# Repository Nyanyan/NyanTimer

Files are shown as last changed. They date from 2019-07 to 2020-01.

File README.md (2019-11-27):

# NyanTimer
DIY Stackmat Timer for cubing

**日本語は下部にあります。**



<!-- TOC -->

- [NyanTimer](#nyantimer)
    - [オープンソースバージョンの使い方](#オープンソースバージョンの使い方)
        - [電池](#電池)
        - [電源](#電源)
        - [ボタン](#ボタン)
        - [タイマースタート・ストップ](#タイマースタート・ストップ)
        - [インスペクションタイム計測](#インスペクションタイム計測)
        - [ラップタイム計測](#ラップタイム計測)
        - [ハック](#ハック)
        - [NyanTimerライブラリ](#nyantimerライブラリ)
    - [開発環境](#開発環境)
    - [技術的な解説](#技術的な解説)
        - [ハードウェア](#ハードウェア)
            - [ボディ](#ボディ)
            - [タッチセンサ](#タッチセンサ)
            - [その他の入出力部品](#その他の入出力部品)
        - [ソフトウェア](#ソフトウェア)
            - [全体的な処理](#全体的な処理)
            - [信号](#信号)
    - [ファイル](#ファイル)
        - [board](#board)
        - [body](#body)
        - [program](#program)
        - [README](#readme)
    - [参考資料](#参考資料)

<!-- /TOC -->

## オープンソースバージョンの使い方

### 電池

左右にある写真の蓋を取って、CR2450を入れます。

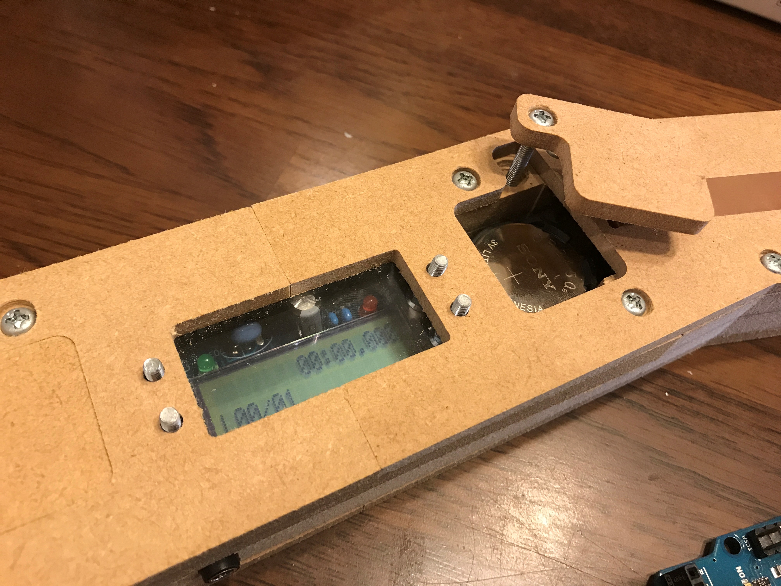
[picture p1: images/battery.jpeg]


ちょっと蓋が取りにくいです。裏側に出ているネジを押しつつ表側でネジの上を押さえると取りやすいです。

### 電源

タイマーにあるスライドスイッチで電源が入ります。これも少し扱いにくいです(ごめんなさい)

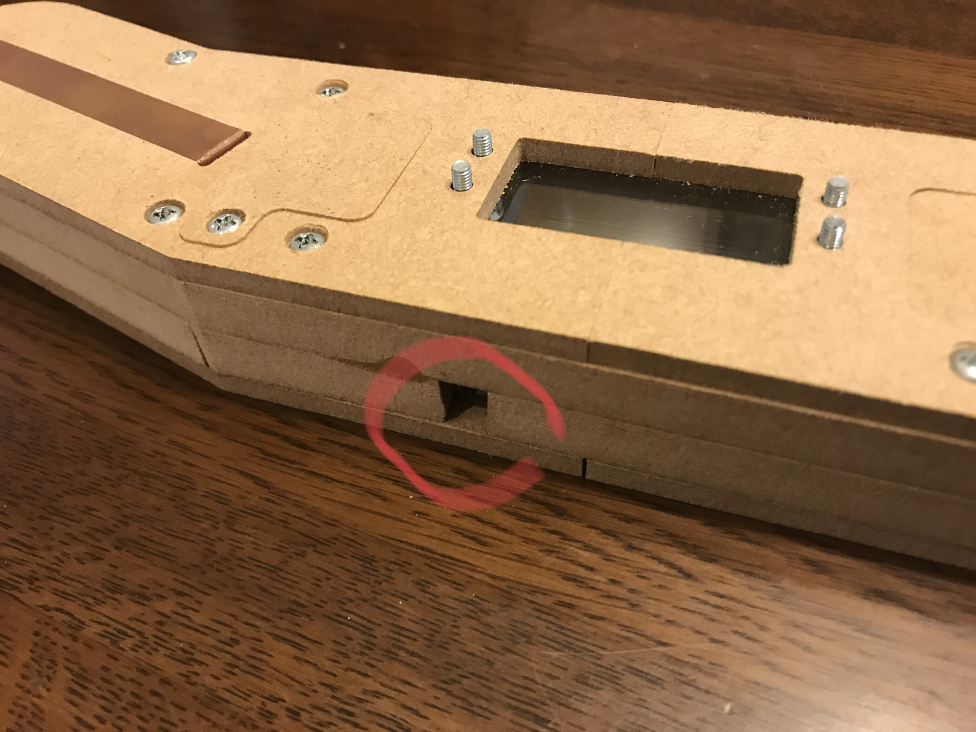
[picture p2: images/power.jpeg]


秋月にいい感じのスイッチが見当たらなくて…

### ボタン

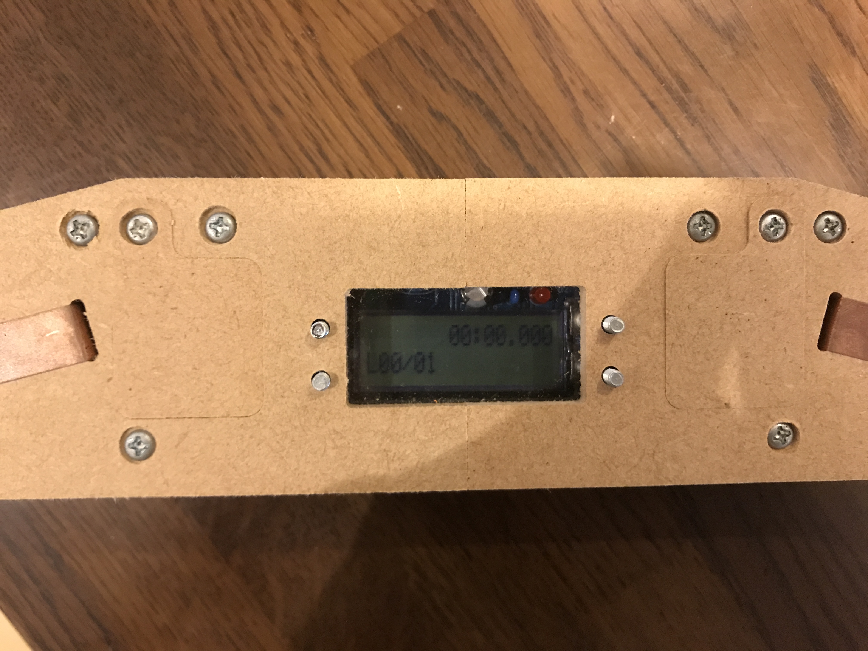
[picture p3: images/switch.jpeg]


* 左上: インスペクションタイム計測モード切り替え

* 左下: タイムリセット

* 右上: ラップ計測回数調整(アップ)

* 右下: ラップ計測回数調整(ダウン)

### タイマースタート・ストップ

manualをご覧ください。

### インスペクションタイム計測

manualをご覧ください。

### ラップタイム計測

manualをご覧ください。

### ハック

manualをご覧ください。

### NyanTimerライブラリ

manualをご覧ください。

## 開発環境

Visual Studio Code

Arduino IDE

Autodesk Eagle

Autodesk Fusion 360

## 技術的な解説

### ハードウェア

基板について詳しいことはboard-vXの中のEagleのデータをご覧ください(回路図描くのが下手でごめんなさい)。簡単に説明すると、Arduinoから各部品に接続しているだけです。

ボディとタッチセンサについてのみ、少し細かく説明をします。その後、その他の部品の概要を少し書きます。

####  ボディ

ボディはAutodesk Fusion 360で設計し、CNCフライス盤で切り出しました ~~(今後レーザーカッターでの出力に方針転換する予定)~~  今後は3Dプリンタで試作した後、金型作って大量生産する予定です。

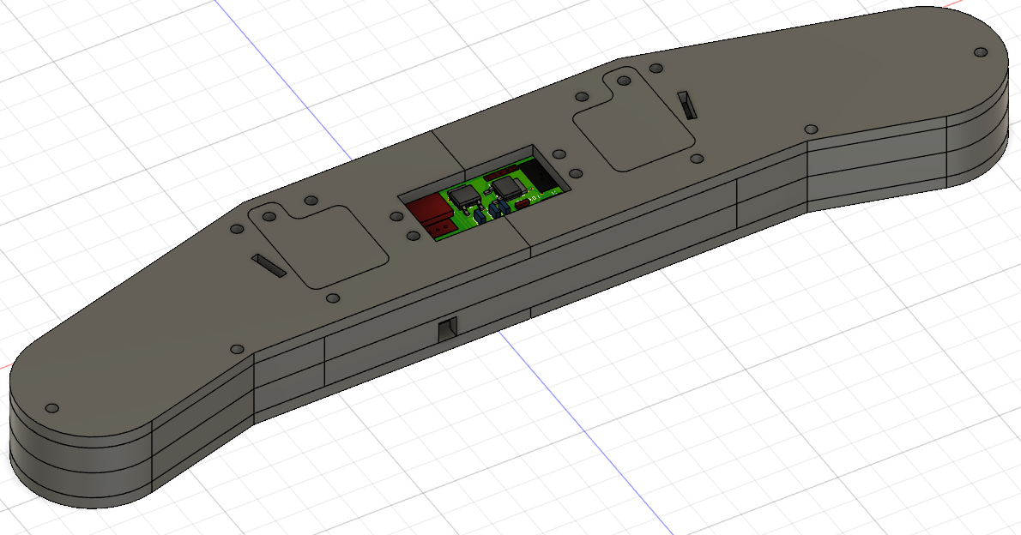
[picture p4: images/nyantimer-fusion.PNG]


#### タッチセンサ

スタックタイマーのタッチセンサは静電容量方式のセンサです。これについて、今回は自作しました。

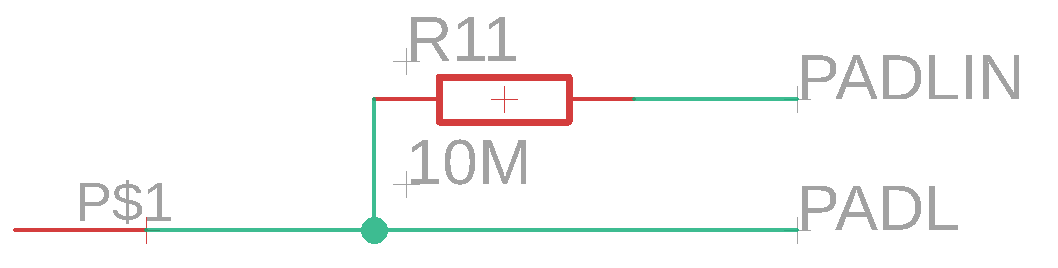
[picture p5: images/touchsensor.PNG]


少々図が汚いですが勘弁してください。

この図でP$1となっているところがタッチパッドの部分です。PADLINから5Vを定期的に入れて、PADLにかかる電圧を調べます。この時、タッチパッドに手を置いているとタッチパッドと手とがそれぞれ極板となって擬似的なコンデンサが成立し、このコンデンサを充電することになります。そのためにPADLがHIGHになるまでの時間が延び、タッチパッドに手が置かれたことを判定できます。

詳しい静電容量方式のセンサについては以下を参照してください。

https://www.fujiele.co.jp/semiconductor/ti/tecinfo/news201707210000/

http://nn-hokuson.hatenablog.com/entry/2017/03/22/200454

なお、電池が多少減ってきても正確にタッチセンサが動くよう、電源投入時にPADLにかかる電圧を測定し、それに1未満の係数を掛けた値をPADLがHIGHであると判定する閾値にしました。

余談ですが、キューブの大会ではタイマーで1/1000秒まで計測可能であるにも関わらず、公式タイムには1/100秒までしか書きません。この理由を私は詳しく知りませんが、このセンサの「時間を計測することで近接を感知する」特性によるところもあるのではないかと個人的に思っています。

#### その他の入出力部品

ブザー

タクトスイッチ

液晶(16文字x2行)

### ソフトウェア

#### 全体的な処理

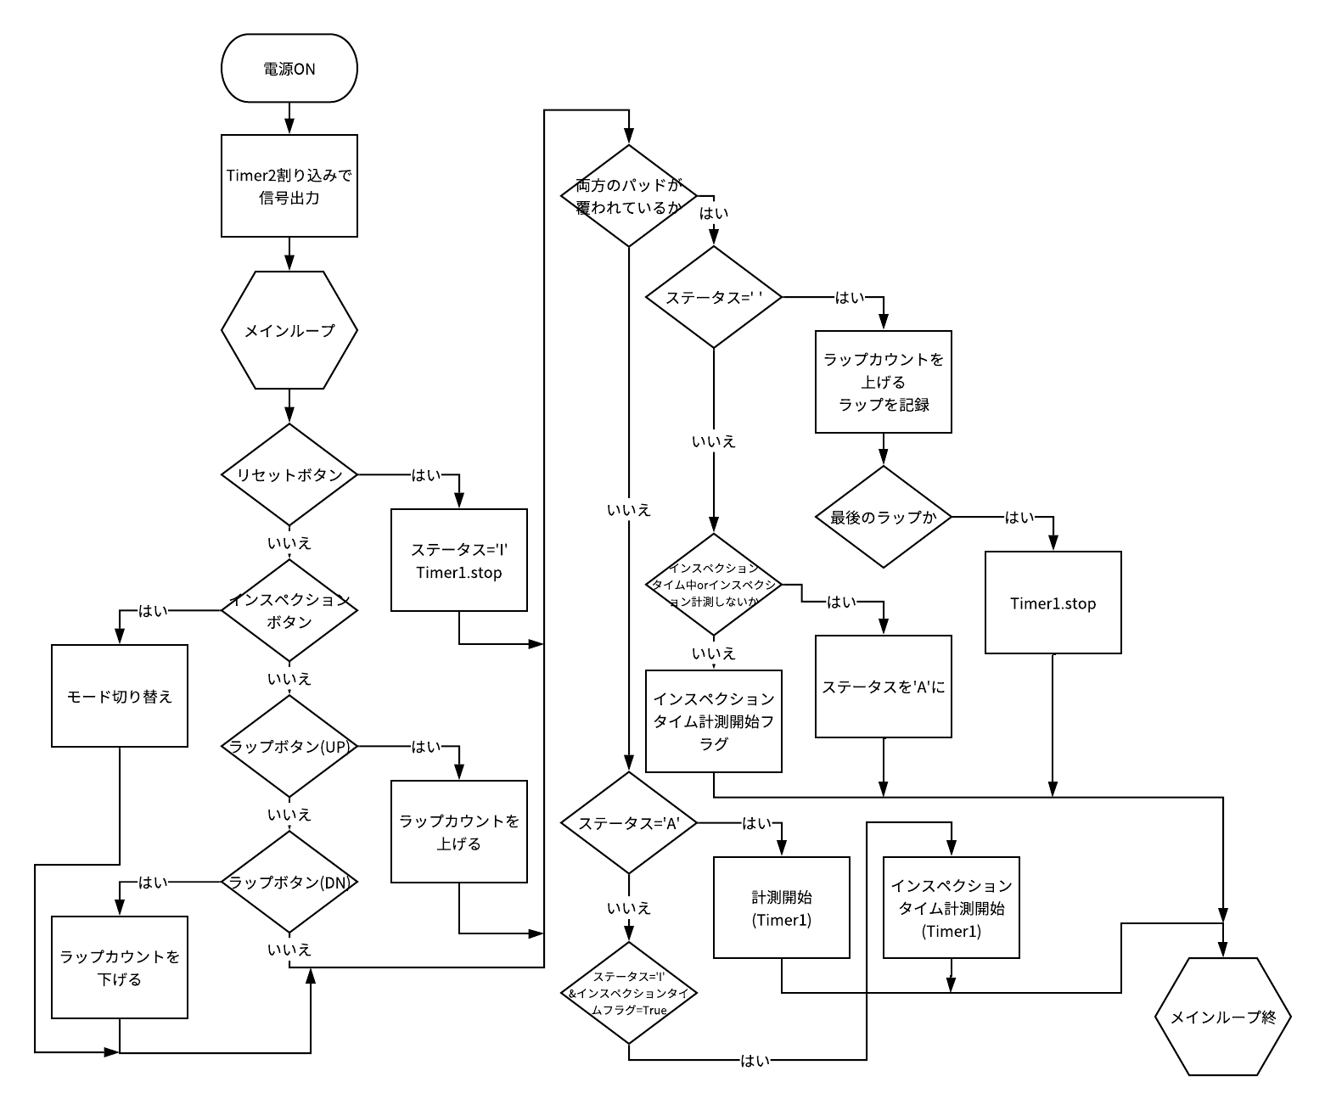
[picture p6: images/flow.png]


なぜか繰り返し記号が使えなかったので適当に六角形で代用です。

プログラム中では左側がbutton()で、右側がtimer()です。

これ以外にも色々複雑に処理はしていますが、まあ大体はこんな感じです。

マイコンは要するにArduinoなので、使えるタイマーはTimer1とTimer2の２つのみです。そのため、Timer2は信号の割り込み処理にずっと使うとして、時間計測とインスペクションタイム計測をTimer1でやっています。

#### 信号

信号はこちらなどを参考にしました。

https://github.com/fw42/atmel/tree/master/stackmat

簡単に日本語で書きます。私は通信には詳しくないので、正確には上を参照してください。

* 信号はRS232
* 1200bps
* データビットは8つ(ステータス、時刻、チェックサム)
* パリティビットなし
* 終了ビットは一つ(LF)

送るデータ

* 1: ステータスのデータ('I', 'A', 'S', 'L', 'R', 'C', ' ')
* 2-7: 時刻のデータ(1:23.45なら‘12345’)
* 8: チェックサム(ASCIIコードで64+タイムの各数字の和, 上の例ならASCIIで79=O)
* 9: CR(ASCIIコード0x0D)
* 10: LF(ASCIIコード0x0A)

1番目、ステータスのデータは、

* ‘I’: タイマー初期化(リセットされた状態)
* ‘A’: タイマースタート直前(パッドを手で押さえて、話したらスタートできる状態)
* ‘ ’: 計測中
* ‘S’: タイム計測完了
* ‘L’: 左パッドが覆われている状態
* ‘R’: 右パッドが覆われている状態
* ‘C’: 両方のパッドが覆われている状態

ただし、NyanTimerでは‘C’は特に必要ないために実装していません(以前は‘R’,‘L’も実装していませんでしたが、CS Timerのインスペクションタイム計測機能であると便利とわかり実装しました)。

## ファイル

### board

基板です。2019/09/05現在、v4-v7までのボードの動作確認がとれています。

### body

外装

Fusion360のファイルとobjとstlファイル

body-v2内のncファイルはPartsTogether内のが最新版です

### program

プログラムとライブラリ

~~中に“calibration”とついたものがありますが、これはタッチセンサで電源投入時に自動でキャリブレーションを行うプログラムです。2019/09/24現在キャリブレーションは試用の機能なので分けて開発しています(Gitを使いこなせていない)~~

2019/10/11追記: キャリブレーション機能はデフォルトの機能になりました。古いプログラムは“archive”内に移動しました。

~~“withfunc”のついたプログラムは、NyanTimer専用関数郡を別に書いたもので、2019/10/11現在試用のプログラムです。~~ 2019/10/14現在、デフォルトのプログラムになりました。

### README

これ

## 参考資料

信号関係(私がまとめた日本語記事): https://qiita.com/Nyanyan_Cube/items/e517e71cf5c4e2aaf1e5

信号関係(英語記事): https://github.com/fw42/atmel/tree/master/stackmat

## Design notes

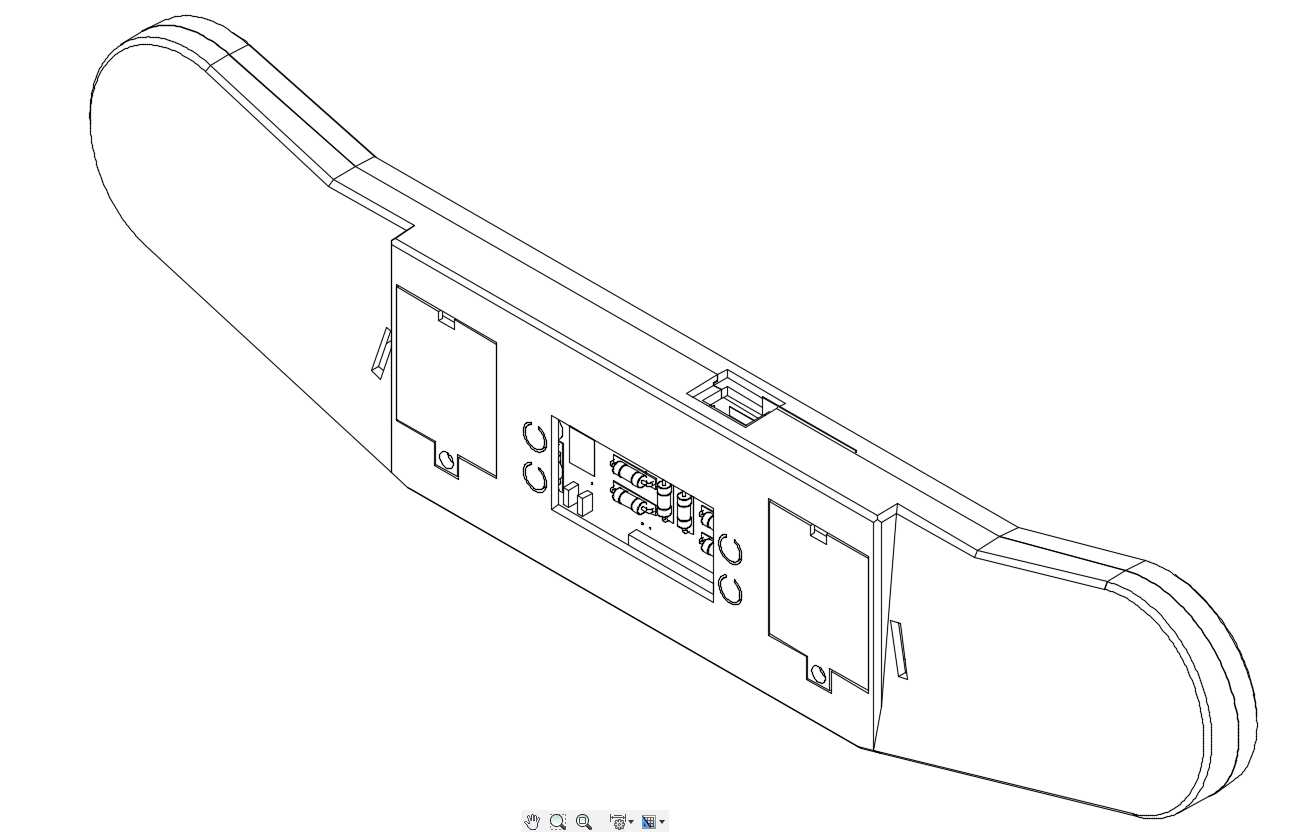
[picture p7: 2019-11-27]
NyanTimer1/images/bodyv4-2.PNG

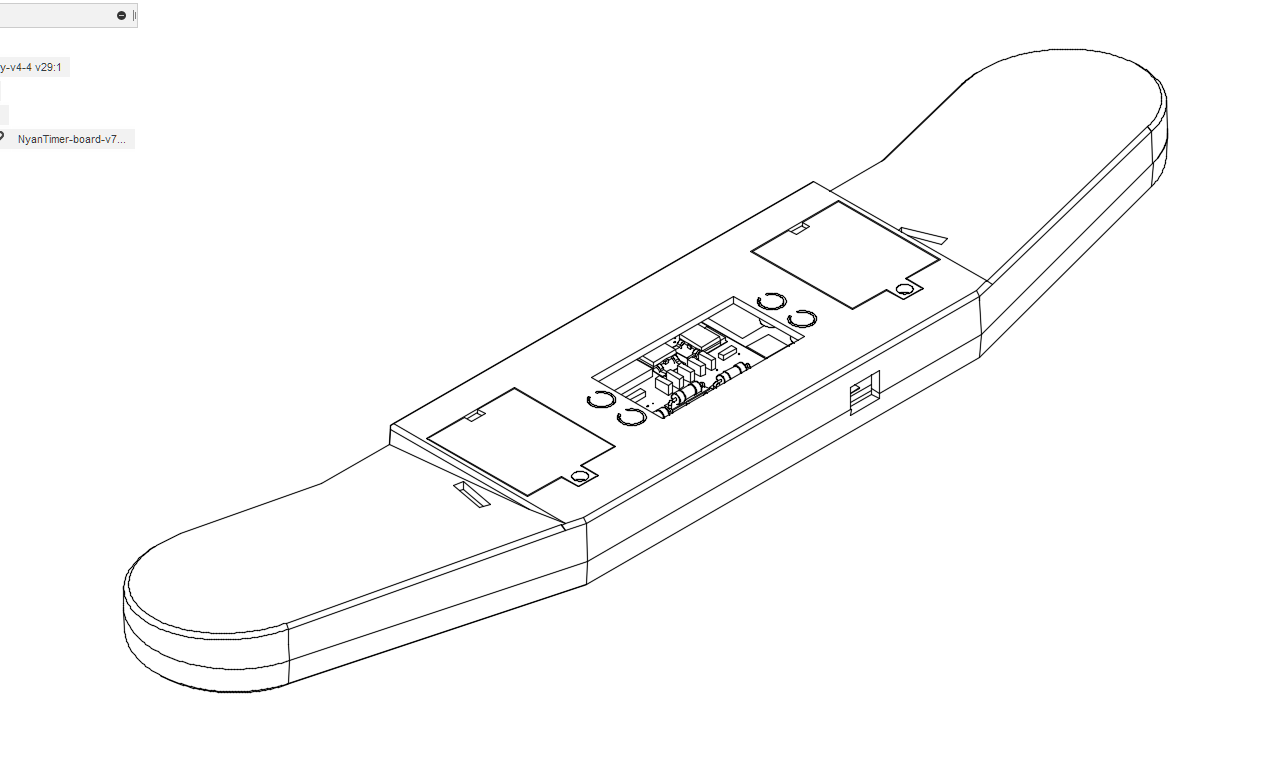
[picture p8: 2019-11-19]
NyanTimer1/images/bodyv4-1.PNG

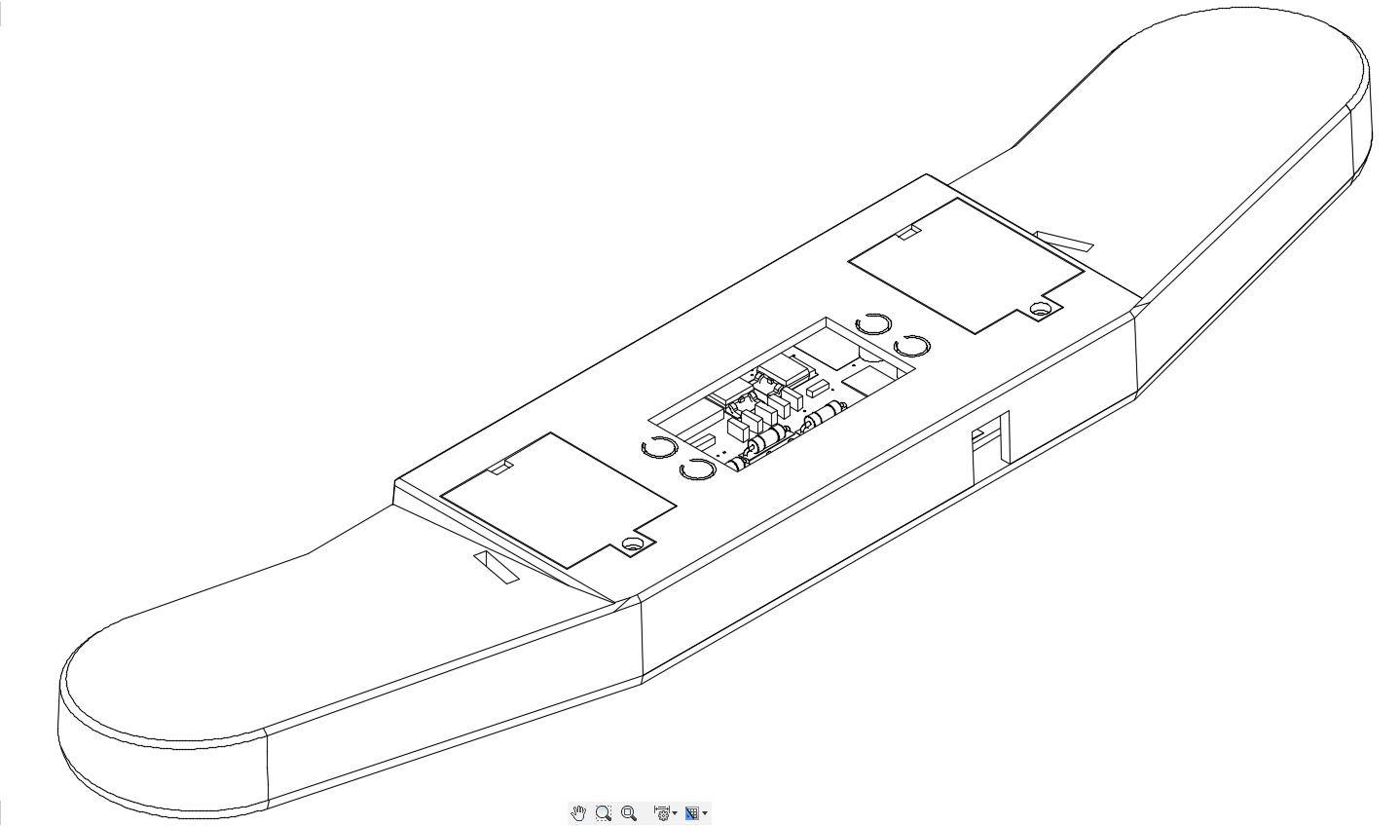
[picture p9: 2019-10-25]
NyanTimer1/images/drawing-bodyv3.PNG

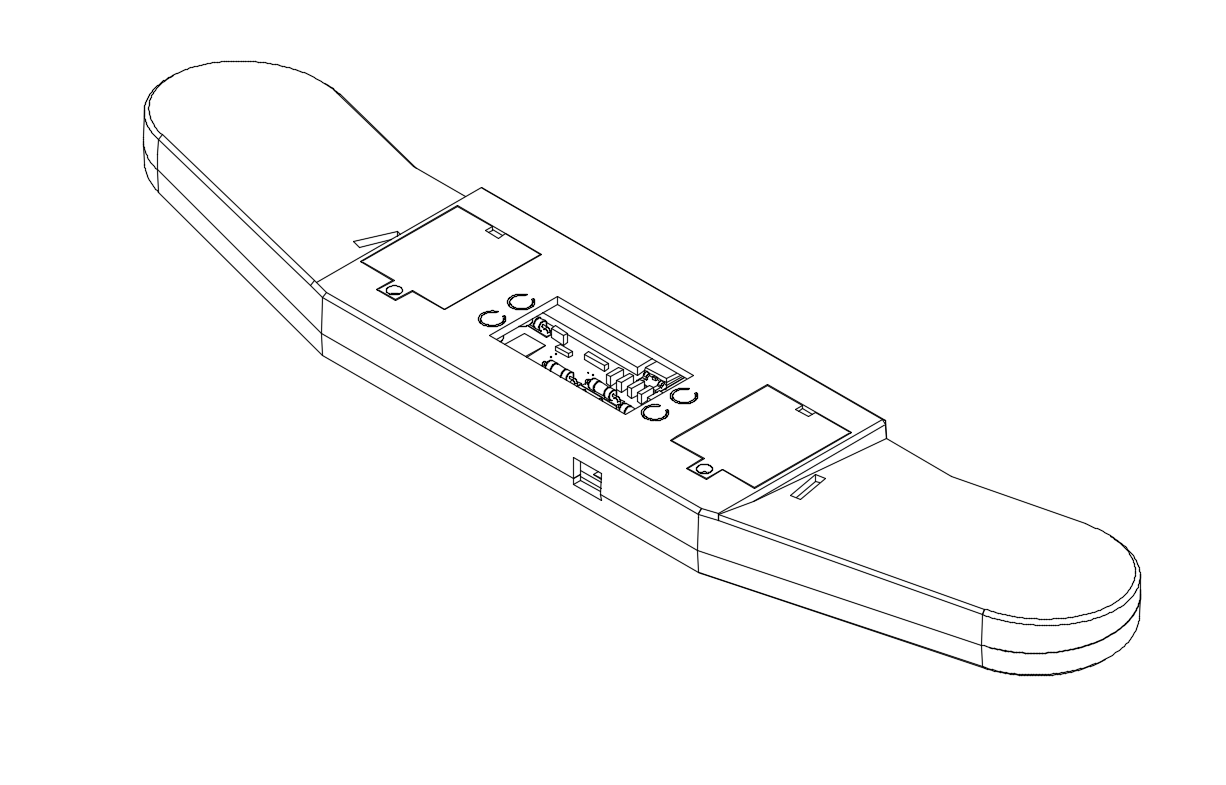
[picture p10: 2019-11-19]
NyanTimer1/images/後.PNG

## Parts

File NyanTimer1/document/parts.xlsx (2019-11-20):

NyanTimer 部品表 | 番号 | 部品名 | 仕様 | 単価 | 個数 | 小計 | URL
 | 1 | ATMEGA328P | ブートローダー書込済 | 320 | 1 | 320 | http://akizukidenshi.com/catalog/g/gI-12774/
 | 2 | 推奨発振子 | 16MHz | 30 | 1 | 30 | http://akizukidenshi.com/catalog/g/gP-08671/
 | 3 | 液晶 | 16x2 | 450 | 1 | 450 | http://akizukidenshi.com/catalog/g/gP-11916/
 | 4 | 電池ボックス | CR2450 | 70 | 2 | 140 | http://akizukidenshi.com/catalog/g/gP-09413/
 | 5 | レギュレータ | 5V | 30 | 1 | 30 | http://akizukidenshi.com/catalog/g/gI-11237/
 | 6 | レギュレータ | 3.3V | 50 | 1 | 50 | http://akizukidenshi.com/catalog/g/gI-11299/
 | 7 | RS232レベル変換IC | ADM3202ANZ | 450 | 0.5 | 225 | http://akizukidenshi.com/catalog/g/gI-03030/
 | 8 | イヤホンジャック |  | 50 | 1 | 50 | http://akizukidenshi.com/catalog/g/gC-02460/
 | 9 | ブザー | 16mm | 100 | 1 | 100 | http://akizukidenshi.com/catalog/g/gP-09644/
 | 10 | LED | 3mm | 10 | 2 | 20 | http://akizukidenshi.com/catalog/g/gI-11577/
 | 11 | タクトスイッチ |  | 10 | 4 | 40 | http://akizukidenshi.com/catalog/g/gP-03647/
 | 12 | スライドスイッチ |  | 30 | 1 | 30 | http://akizukidenshi.com/catalog/g/gP-08789/
 | 13 | 抵抗 | 10k | 1 | 7 | 7
 | 14 | 抵抗 | 1k | 1 | 2 | 2
 | 15 | 抵抗 | 10M | 1 | 2 | 2
 | 16 | コンデンサ | 0.1u | 10 | 12 | 120
 | 17 | コンデンサ | 1u | 10 | 2 | 20
 | 18 | コンデンサ | 2.2u以上 | 10 | 2 | 20
 | 19 | コンデンサ | 0.22u | 10 | 2 | 20
 | 20 | 電池 | CR2450 | 260 | 2 | 520 | https://www.yodobashi.com/product/100000001001156421/

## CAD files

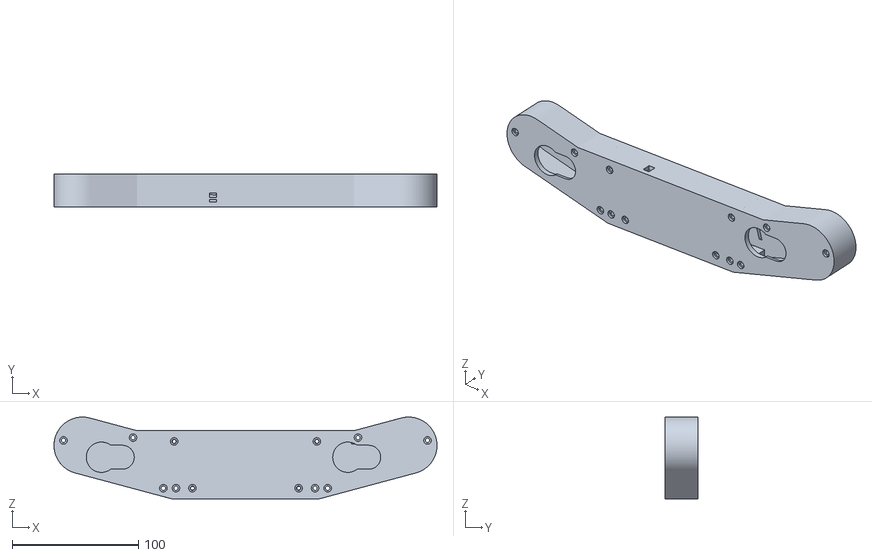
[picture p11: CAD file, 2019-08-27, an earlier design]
NyanTimer1/body/body-v1/body-v1.stl
303.1 x 26.0 x 64.8

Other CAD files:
NyanTimer1/body/body-v2/body-v2.stl
NyanTimer1/body/body-v1/body-v1.obj

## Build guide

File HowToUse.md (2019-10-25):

# NyanTimer
DIY Stackmat Timer for cubing

**日本語は下部にあります。**

<!-- TOC -->

- [NyanTimer](#nyantimer)
    - [Abstract](#abstract)
    - [Functions](#functions)
    - [概要](#概要)
    - [機能](#機能)
    - [使い方](#使い方)
        - [電池](#電池)
        - [電源](#電源)
        - [ボタン](#ボタン)
        - [タイマースタート・ストップ](#タイマースタート・ストップ)
        - [インスペクションタイム計測](#インスペクションタイム計測)
        - [ラップタイム計測](#ラップタイム計測)
        - [ハック](#ハック)
            - [board-v7でのハック](#board-v7でのハック)
        - [NyanTimerライブラリ](#nyantimerライブラリ)
            - [入手](#入手)
            - [必要なライブラリ](#必要なライブラリ)
            - [関数で使用する定数と変数](#関数で使用する定数と変数)
                - [NyanTimerの各ピン](#nyantimerの各ピン)
                - [基礎的な変数](#基礎的な変数)
            - [関数の紹介](#関数の紹介)
    - [開発環境](#開発環境)
    - [技術的な解説](#技術的な解説)
        - [ハードウェア](#ハードウェア)
            - [ボディ](#ボディ)
            - [タッチセンサ](#タッチセンサ)
            - [その他の入出力部品](#その他の入出力部品)
        - [ソフトウェア](#ソフトウェア)
            - [全体的な処理](#全体的な処理)
            - [信号](#信号)
    - [ファイル](#ファイル)
        - [board](#board)
        - [body](#body)
        - [program](#program)
        - [README](#readme)
    - [参考資料](#参考資料)

<!-- /TOC -->

## Abstract

This timer is made by a cuber for cubers, so it has some functions that ordinal timers don’t have: Measuring the inspection time and lap time. These functions are developped with asking cubers on Twitter.

I aim to sell this timer in the future, but on this page, there is enough information you to make one yourself.

If you have any questions, ask me through any medium (Twitter is better).

https://twitter.com/nyanyan_cube

The movie of NyanTimer below:

https://www.youtube.com/watch?v=Nj-br9DjQB4&t=30s

Photos:

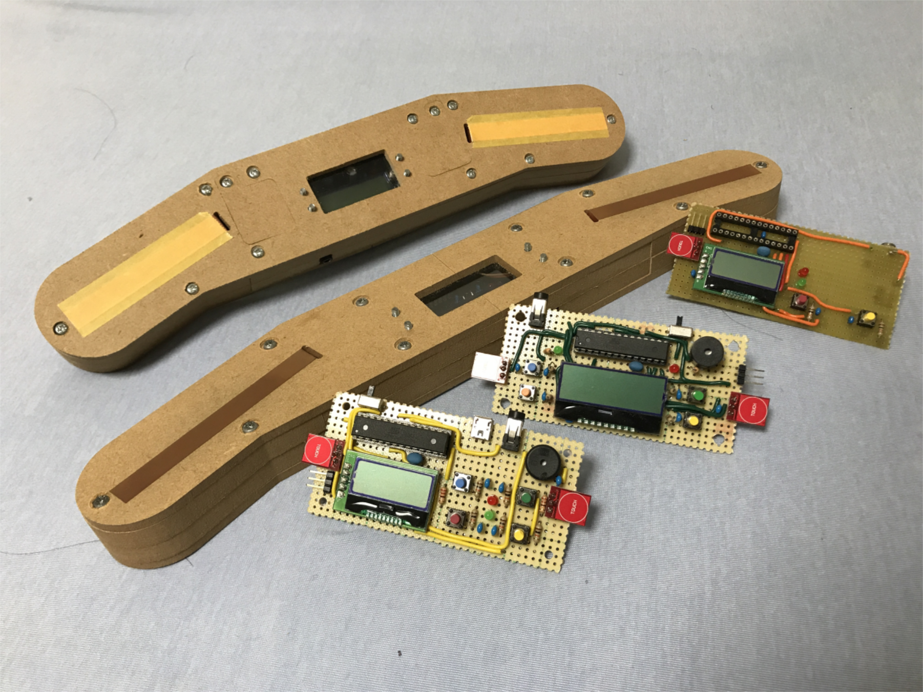
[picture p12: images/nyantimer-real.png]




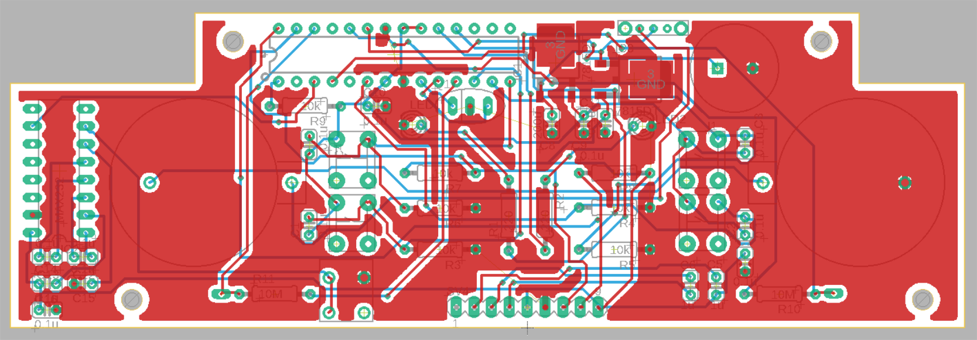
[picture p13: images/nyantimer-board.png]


## Functions

## 概要

このタイマーはキューバー目線をコンセプトに製作したものです。そのため、普通のスタックタイマーにはない2つの大きな追加機能、インスペクションタイム計測とラップタイム計測があります。これらの機能は私がTwitterでキューバーの皆さんに向けて取ったアンケートの結果に基づいてつけた機能です。

本書は製品版NyanTimerの取扱説明書です。

もしご質問等ございましたら(可能な限り)Twitter経由でご連絡ください。

https://twitter.com/nyanyan_cube

NyanTimerの紹介動画のURLを載せておきます。

https://www.youtube.com/watch?v=Nj-br9DjQB4&t=30s

画像







## 注意

以下の注意を疎かにした場合、重大な事故につながる可能性があります。

* 

## 機能

* 標準のスタックタイマーの機能(信号出力を含む)
* インスペクションタイム計測(秒数を知らせる機能を含む)
* ラップタイム計測(99個まで計測可能)

## 使い方

### 電池

左右にある写真の蓋を取って、CR2450を入れます。

ちょっと蓋が取りにくいです。裏側に出ているネジを押しつつ表側でネジの上を押さえると取りやすいです。

### 電源

タイマーにあるスライドスイッチで電源が入ります。これも少し扱いにくいです(ごめんなさい)



秋月にいい感じのスイッチが見当たらなくて…

### ボタン



* 左上: インスペクションタイム計測モード切り替え

* 左下: タイムリセット

* 右上: ラップ計測回数調整(アップ)

* 右下: ラップ計測回数調整(ダウン)

### タイマースタート・ストップ

両方のパッドを覆うと赤いLEDが点灯します。そのまま覆い続けると緑色のLEDが点き、パッドから手を話すと計測が開始します。

計測中に両方のパッドに手を置くとタイマーはストップします。

### インスペクションタイム計測

インスペクションタイム計測モード切り替えボタンを押すと、画面左上に‘I’や‘Is’が表示されたり消えたりします。これらの表示について、示す機能は以下です。

* ‘ ’: インスペクションタイムを計測しない
* ‘I’: インスペクションタイム計測(8秒、12秒のコールなし)
* ‘Is’: インスペクションタイム計測(8秒、12秒で音が鳴る)

両方のパッドを覆って1秒弱すると赤いLEDが点灯します。この状態で手を離すとインスペクションタイムの計測が開始します。‘Is’モードでは8秒と12秒で電子音が鳴ります。

### ラップタイム計測

ラップタイム計測回数調整ボタンを押して目的のラップタイムに設定してください。

このボタンは押し続けると高速で数字が変わります。

タイム計測中に両方のパッドを覆うと区間タイムが画面右下に表示されます。

タイム計測終了後にラップ計測回数調整ボタンを押すと各区間タイムが確認できます。

ラップタイムは99個まで設定可能です。

### ハック

これはある程度組み込み技術に精通した人が行ってください。

NyanTimer board-v7以降のボードではNyanTimerのプログラムを簡単に変更できるようになっています。これを使ってソフトウェアアップデートを実行したり、このGitHubを見つつ自分好みにプログラムを変更できたりします。

なお、構想段階のboard-v8ではUSBシリアル変換を基板に載せることも考えているので、もっと簡単にハックできるかもしれません。

#### board-v7でのハック

まず裏側のネジを全て取り外し、内部の基板を見ます。基板左上にUSBシリアル変換接続端子があります。

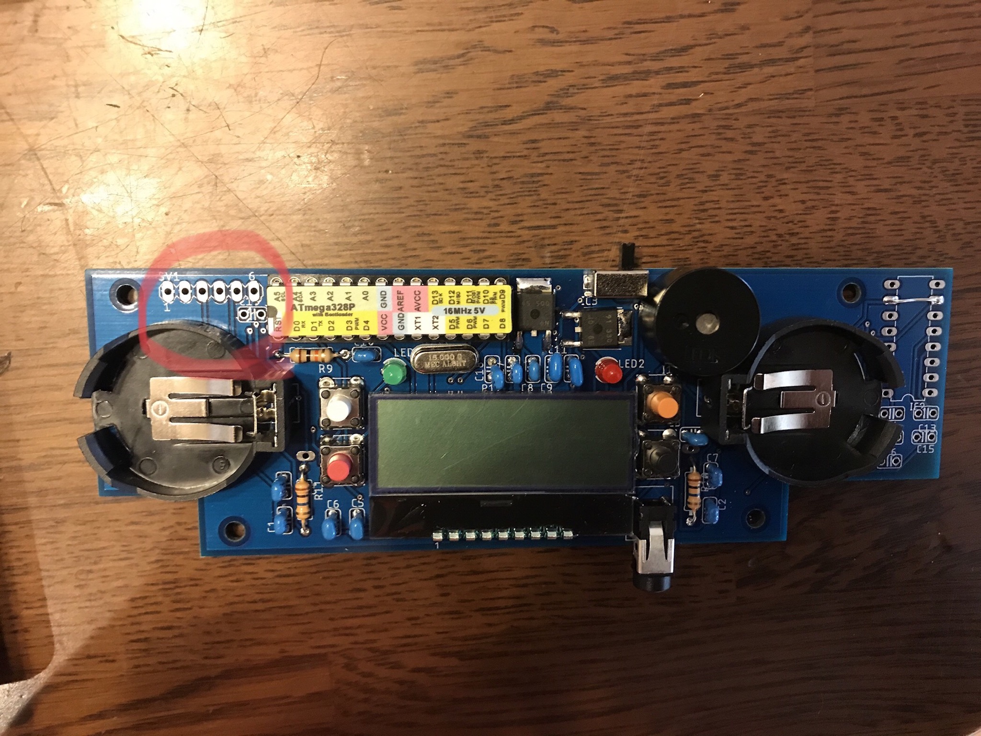
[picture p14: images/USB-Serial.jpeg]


1. コンデンサ取付部に0.1uFのコンデンサを取り付けます
2. ピンヘッダ取付部に6Pピンヘッダを取り付けます
3. USBシリアル変換を挿します

使うUSBシリアル変換にはこちらを推奨します(動作確認はこちらで行いました)。

https://www.switch-science.com/catalog/1032/

各ピンは上から見て左(1ピン)から、

GND-CTS-VCC-TX-RX-DTR

です。

### NyanTimerライブラリ

NyanTimerのハックにあたって必要となるであろう関数をまとめてライブラリとして提供しています。

#### 入手

このGitHub内のNyanTimer/program/library/内の“NyanTimer”がライブラリです。このままダウンロードしてご自身のライブラリフォルダに入れて使ってください。

#### 必要なライブラリ

NyanTimerには前提として必要なライブラリがあります。以下のライブラリをインストールしておいてください。最近のArduinoライブラリではメニューバーの“スケッチ->ライブラリをインクルード->ライブラリを管理“から大抵のライブラリはインストールできますが、2019/10/13現在ST7032ライブラリのみインターネットから自分で取ってくる必要があります。

* TimerOne
  https://www.arduinolibraries.info/libraries/timer-one
* MsTimer2
  https://playground.arduino.cc/Main/MsTimer2/
* Wire
  標準ライブラリです。
* ST7032
  https://ore-kb.net/archives/195

#### 関数で使用する定数と変数

関数として使っている定数と変数についての解説です。関数内でstaticになっているものは解説しません。

##### NyanTimerの各ピン

以下のものです

* **BUTTON1**
  リセットボタン
* **BUTTON2**
  インスペクションモードボタン
* **BUTTON3**
  ラップのカウントアップボタン
* **BUTTON4**
  ラップのカウントダウンボタン
* **BUZZER**
  ブザー(HIGHにするだけで勝手に鳴ります)
* **LEDR**
  赤色LED
* **LEDG**
  緑色LED
* **PAD1OUT**
  右パッドの出力ピン
* **PAD1IN**
  右パッドの入力ピン
* **PAD2OUT**
  左パッドのっ出力ピン
* **PAD2IN**
  左パッドの入力ピン

なお、PAD1OUT, PAD1IN, PAD2OUT, PAD2INについて、ユーザが直接触ることはないと思います。

##### 基礎的な変数

以下のものです。

* **int output[7]**
  シリアル出力をする際に時間情報を格納しておく配列。長さは7
* **char statout**
  シリアル出力をする際のステータス
* **char stat**
  ステータス情報。statoutと大体同じだが時々違う
* **int minute, second, msecond**
  時間。分秒ミリ秒

#### 関数の紹介

全ての関数は必ず

```Python
NyanTimer::function(argments);
```

の形で使ってください。

* **void begin()**

NyanTimerの初期処理関数です。必ずvoid setup()の中で実行してください。

* **void lightLED(int LED, bool HL)**

LEDを光らせる関数です。LEDにLEDGまたはLEDR、HLにtrue(点灯)またはfalse(消灯)を入力します。

* **void printLCD(int row, int col, String str)**

LCDになにか文字を表示する関数です。rowで表示する段(0か1)、colで表示開始列(0-15)を選択し、strを表示します。

* **void startTimer(int msec, void function())**

タイマーをスタートさせる関数です。内部はMsTimer2の関数で構成されています。

msecにインターバルをミリ秒で入力し、functionに実行する関数を入力します。この関数を実行すると即座にタイマーがスタートします。

* **void stopTimer()**

タイマーをストップします。

* **int touch(int mode)**

タッチパッドの情報を得る関数です。modeについて解説します。

**mode == 0**

返す数字が

0: どちらのパッドもタッチされていないまたはお片方のパッドがタッチされている場合

1: 両方のパッドがタッチされた場合

**mode == 1**

0: どちらのパッドもタッチされていない場合

1: 両方のパッドがタッチされている場合

2: 右パッドがタッチされている場合

3: 左パッドがタッチされている場合

* **void calcTime(int minute, int second, int msecond, int output)**

minute(分), second(秒), msecond(ミリ秒)の情報から、LCDへの出力に使いやすい時間配列を作ります。なお、output配列(長さ7)の内容を破壊的に変更します。

* **String strTime(int input[])**

input配列(長さ7)の情報から、LCDに出力する時に使うString文字列を作成します。

* **bool inputButton(int n)**

ボタンが押されればtrue、押されていなければfalseを返す関数です。

nにBUTTON1などを入力します。

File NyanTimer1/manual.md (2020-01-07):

# NyanTimer Manual
DIY Stackmat Timer for cubing

**日本語は下部にあります。**

<!-- TOC -->

- [NyanTimer Manual](#nyantimer-manual)
    - [Abstract](#abstract)
    - [Caution](#caution)
    - [Functions](#functions)
    - [Name of each part](#name-of-each-part)
        - [Name of each button](#name-of-each-button)
    - [Powering the timer](#powering-the-timer)
        - [Batteries](#batteries)
        - [Powering](#powering)
    - [Measure the time](#measure-the-time)
        - [Start & Stop the timer](#start--stop-the-timer)
        - [Sounding when timer stops](#sounding-when-timer-stops)
        - [Measuring the inspection time](#measuring-the-inspection-time)
        - [Measuring lap times](#measuring-lap-times)
        - [Auto power saving mode](#auto-power-saving-mode)
    - [Hack](#hack)
        - [How to hack](#how-to-hack)
        - [NyanTimer library](#nyantimer-library)
            - [How to get](#how-to-get)
            - [Libraries used in NyanTimer library](#libraries-used-in-nyantimer-library)
            - [Constants and variables](#constants-and-variables)
                - [Constants (Pins of NyanTimer)](#constants-pins-of-nyantimer)
                - [Variables](#variables)
            - [Functions](#functions)
    - [概要](#概要)
    - [注意](#注意)
    - [大きな機能](#大きな機能)
    - [各部名称](#各部名称)
        - [ボタン名称](#ボタン名称)
    - [電源を入れる](#電源を入れる)
        - [電池](#電池)
        - [電源](#電源)
    - [時間を計測する](#時間を計測する)
        - [タイマースタート・ストップ](#タイマースタート・ストップ)
        - [計測終了時の音声出力](#計測終了時の音声出力)
        - [インスペクションタイム計測](#インスペクションタイム計測)
        - [ラップタイム計測](#ラップタイム計測)
        - [オートパワーセーブ](#オートパワーセーブ)
    - [ハック](#ハック)
        - [やり方](#やり方)
        - [NyanTimerライブラリ](#nyantimerライブラリ)
            - [入手](#入手)
            - [必要なライブラリ](#必要なライブラリ)
            - [関数で使用する定数と変数](#関数で使用する定数と変数)
                - [NyanTimerの各ピン](#nyantimerの各ピン)
                - [基礎的な変数](#基礎的な変数)
            - [関数の紹介](#関数の紹介)

<!-- /TOC -->

## Abstract

This timer is made by a cuber for cubers, so it has some functions that ordinal timers don’t have: Measuring the inspection time and lap time. These functions are developped with asking cubers on Twitter.

I aim to sell this timer in the future, but on this page, there is enough information you to make one yourself.

This is an instruction manual for NyanTimer.

If you have any questions, ask me through any medium (Twitter is better).

https://twitter.com/nyanyan_cube

The movie of NyanTimer below:

https://youtu.be/ierR8ZPBncU

## Caution

If you break these promises, you might be in an accident.

* Use the timer after reading this manual.
* Do not shock the timer.
* This timer can cause a trouble after about 50000 measurement because of the micro controller.
* If you disassemble or hack the timer, we won’t take the responsibility.

## Functions

*  Functions of ordinal stack mat timers (including signal out)
* Inspection time measurement (including 8, 12, 15, and 17s call)
* Lap time measurement (Max 99 laps)

## Name of each part

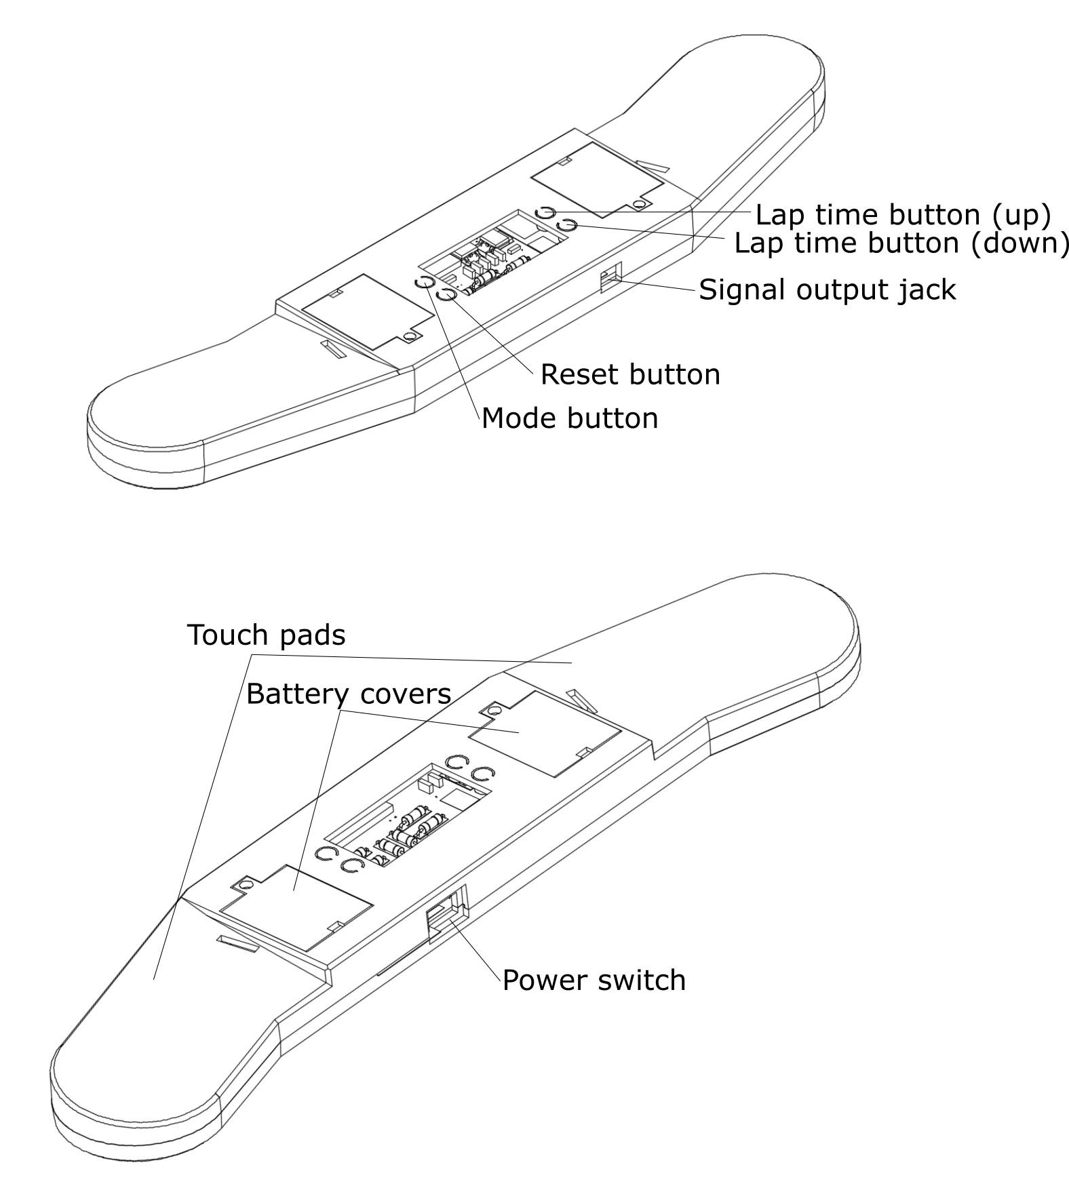
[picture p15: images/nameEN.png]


### Name of each button

* Upper left: Mode button
* Bottom left: Reset button
* Upper right: Lap time button (up)
* Bottom right: Lap time button (down)

## Powering the timer

### Batteries

Remove the battery covers, then put two CR2450s.

### Powering

Slide the power switch.

## Measure the time

### Start & Stop the timer

Covering both pads, and the red LED lights. Then wait, and both red and green LEDs lights. If you release your hand, then timer starts.

When you cover the both pads during timing, the timer stops.

If you measure the lap times (when the LCD shows a number of lap except ‘1’), We strongly recommend not to cover one pad when timing.

### Sounding when timer stops

If you want the timer to sound when you stop the timer, press mode button a second. Then the LCD shows ‘S’ or nothing on the upper left.

* ‘ ’: No sound when timer stops
* ‘S’: Sounds when timer stops

### Measuring the inspection time

If you press mode button, the LCD shows ‘i’, ‘I’, or nothing on the upper left. These messages tells you:

* ‘ ’: Not measure the inspection time
* ‘i’: Measure the inspection time (no 8s, 12s, +2, DNF calls)
* ‘I’: Measure the inspection time (with 8s, 12s, +2, DNF calls)

On ‘i’ or ‘I’ mode, when you cover the both pads and wait about 1 second, the red LED lights. Then when you release, the inspection time starts.

### Measuring lap times

Press lap time button (up and down) and adjust the count of lap. If you press this button for long, the number will change quickly.

If you cover one or two pad during timing, lap time will be shown on the bottom right of the LCD.

After finishing timing, you can check each lap time with lap time buttons.

Max lap is 99.

### Auto power saving mode

If you leave this timer for about 5 minutes, it will be in power saving mode. To cancel this, slide the power switch and repower it.

## Hack

In this timer, ATMEGA328P (Arduino Uno) is used. So you can easily hack it.

### How to hack

Only people who are familiar to embedded technology should do this. And we will have no responsibility to this.

NyanTimer’s program is easy to edit, because of the hardware. You can update the firmware and edit the program with this repository.

First, take all the screws and see the board. On the upper left of the board, there is pins of USB-Serial conversion.



1. Put 0.1uF condenser
2. Put a 6P pin header
3. Connect your USB-Serial conversion

We recommend you to use this one:

https://www.switch-science.com/catalog/1032/

pins are: from pin 1 (left), 

GND-CTS-VCC-TX-RX-DTR

### NyanTimer library

We published a library in order you to hack it.

#### How to get

program/libraries/NyanTimer on this GitHub is it. Download this and unzip it on your libraries folder.

#### Libraries used in NyanTimer library

NyanTimer uses some other libraries. Before hacking it, you must install these libraries below: 

* TimerOne
  https://www.arduinolibraries.info/libraries/timer-one
* MsTimer2
  https://playground.arduino.cc/Main/MsTimer2/
* SoftI2CMaster
  https://github.com/felias-fogg/SoftI2CMaster
* ST7032_SoftI2CMaster
  I modified this(https://ore-kb.net/archives/195). program/libraries/ST7032_SoftI2CMaster on this GitHub is it.

#### Constants and variables

All constants and variables must be used like this:

```c++
NyanTimer::constantsOrVariables
```

Constants and variables used in this library are below:

##### Constants (Pins of NyanTimer)

* **BUTTON1**
  Reset button
* **BUTTON2**
  Mode button
* **BUTTON3**
  Lap time button (up)
* **BUTTON4**
  Lap time button (down)
* **BUZZER**
  Buzzer (Sound when the pin is HIGH)
* **LEDR**
  Red LED
* **LEDG**
  Green LED
* **PAD1OUT**
  Output pin of right pad
* **PAD1IN**
  Input pin of right pad
* **PAD2OUT**
  Output pin of left pad
* **PAD2IN**
  Input pin of left pad

Users might not use PAD1OUT, PAD1IN, PAD2OUT, PAD2IN

##### Variables

* **int output[7]**
  An array, the information of time will be in it to output the signal and output on the LCD.
* **char stat**
  Status
* **int minute, second, msecond**
  Time, minute, second, milli second
* **batterycount**
  A variable for auto power saving 

#### Functions

All functions must be used like this:

```c++
NyanTimer::function(argments);
```

* **void begin(bool signal)**

Setting of NyanTimer. Must be done in void setup(). Argment is about signal output; true: output, false: no signal output.

**void timing()**

This function do timing. Must be done in void loop or something else.

* **void lightLED(int LED, bool HL)**

A function to light a LED. In ‘LED’, there will be LEDG or LEDR, in ‘HL’, true (on) or false (off).

* **void printLCD(int row, int col, String / char str)**

A function to show something on the LCD. In ‘row’, select the row (0 or 1), in ‘col’, select the column(0-15). On the LCD, ‘str’ will be written. ‘str’ must be char or String.

* **void startTimer(int msec, void function())**

Start the timer. This function is made of MsTimer2.

Input interval (milli second) on ‘msec’, and put the function to execute on ‘function’.

* **void stopTimer()**

Stop the timer.

* **int touch()**

Returns the status of touchpad. Returning number means:

0: Neither pad is covered

1: Both pads are covered

2: Only right pad is covered

3: Only left pad is covered

* **void calcTime(int minute, int second, int msecond, int output)**

From minute, second, msecond, make an array that enable you to output the signal or output on the LCD. This function changes ‘output’ aarray.

* **String strTime(int input[])**

From ‘input’ array, make a string. this string will be used to output on the LCD.

* **bool inputButton(int button)**

If ‘button’ is pressed, returns true. 

* **void setLCDclear(int mode)**

Clear the LCD. mode == 0: upper row, mode == 1: lower row, mode ==  2: both row, are cleared.

* **void powersave()**

Power saving function.

---

---

---

## 概要

このタイマーはキューバー目線をコンセプトに製作したものです。そのため、普通のスタックタイマーにはない2つの大きな追加機能、インスペクションタイム計測とラップタイム計測があります。これらの機能は私がTwitterでキューバーの皆さんに向けて取ったアンケートの結果に基づいてつけた機能です。

本書は製品版NyanTimerの取扱説明書です。

もしご質問等ございましたら(可能な限り)Twitter経由でご連絡ください。

https://twitter.com/nyanyan_cube

NyanTimerのPVのURLを載せておきます。

https://youtu.be/ierR8ZPBncU

## 注意

以下の注意を疎かにした場合、重大な事故につながる虞があります。

* 必ず本取扱説明書を読んでから使用すること。
* 製品に衝撃を与えないこと
* 本製品はマイコンの仕様上、約50000回の計測で不具合を起こす可能性があります。
* 製品の分解・改造について製造者は責任を負いません。

## 大きな機能

* 標準のスタックタイマーの機能(信号出力を含む)
* インスペクションタイム計測(秒数を知らせる機能を含む)
* ラップタイム計測(99個まで計測可能)

## 各部名称

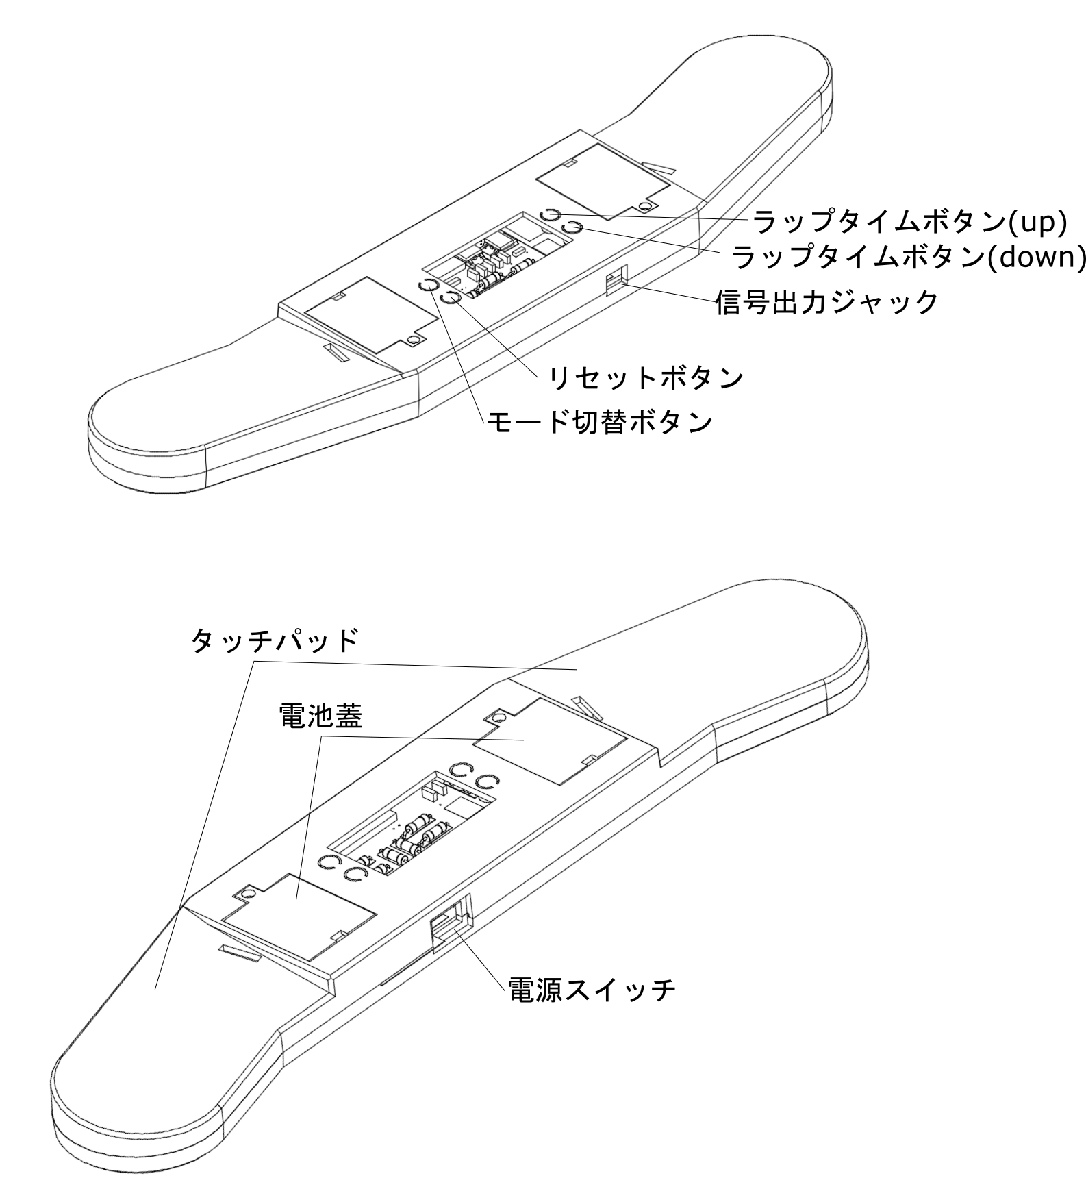
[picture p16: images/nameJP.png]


### ボタン名称

* 左上: モード切り替えボタン
* 左下: タイムリセットボタン
* 右上: ラップ計測回数調整(アップ)ボタン
* 右下: ラップ計測回数調整(ダウン)ボタン

## 電源を入れる

### 電池

左右の電池蓋のネジを外して蓋を取って、CR2450を入れます。

### 電源

タイマーにあるスライドスイッチで電源が入ります。

## 時間を計測する

### タイマースタート・ストップ

両方のパッドを覆うと赤いLEDが点灯します。そのまま覆い続けると緑色のLEDが点き、パッドから手を話すと計測が開始します。

計測中に両方のパッドに手を置くとタイマーはストップします。

ラップタイム計測をする場合(ラップタイム表示が1以外の場合)はタイマーから両手を離すことを強く勧めます。

### 計測終了時の音声出力

モード切替ボタンを長押しすると画面に‘S’の文字が出現したり消えたりします。これらの表示について、示す機能は以下です。

* ‘ ‘:計測終了時に音が鳴らない
* ’S’: 計測終了時に音が鳴る

### インスペクションタイム計測

モード切り替えボタンを押すと、画面左上に‘i’や‘I’が表示されたり消えたりします。これらの表示について、示す機能は以下です。

* ‘ ’: インスペクションタイムを計測しない
* ‘i’: インスペクションタイム計測(8秒、12秒、+2、DNFのコールなし)
* ‘I’: インスペクションタイム計測(8秒、12秒、+2、DNFで音が鳴る)

両方のパッドを覆って1秒弱すると赤いLEDが点灯します。この状態で手を離すとインスペクションタイムの計測が開始します。

### ラップタイム計測

ラップタイム計測回数調整ボタンを押して目的のラップタイムに設定してください。

このボタンは押し続けると高速で数字が変わります。

タイム計測中に片方または両方のパッドを覆うと区間タイムが画面右下に表示されます。

タイム計測終了後にラップ計測回数調整ボタンを押すと各区間タイムが確認できます。

ラップタイムは99個まで設定可能です。

### オートパワーセーブ

計測をしていない状態で5分程度放置すると自動的に画面が消え、パワーセーブモードに入ります。解除するには電源を入れ直します。

## ハック

このタイマーはCPUにATMEGA328P(Arduino Uno)を使用しています。そのため、簡単にハックすることができます。

### やり方

これはある程度組み込み技術に精通した人が行ってください。なお、ハックによる不具合について製造元は保証しません。

NyanTimerはプログラムを簡単に変更できるようになっています。これを使ってソフトウェアアップデートを実行したり、このGitHubを見つつ自分好みにプログラムを変更できたりします。

まず裏側のネジを全て取り外し、内部の基板を見ます。基板左上にUSBシリアル変換接続端子があります。



1. コンデンサ取付部に0.1uFのコンデンサを取り付けます
2. ピンヘッダ取付部に6Pピンヘッダを取り付けます
3. USBシリアル変換を挿します

使うUSBシリアル変換にはこちらを推奨します(動作確認はこちらで行いました)。

https://www.switch-science.com/catalog/1032/

各ピンは上から見て左(1ピン)から、

GND-CTS-VCC-TX-RX-DTR

です。

### NyanTimerライブラリ

NyanTimerのハックにあたって必要となるであろう関数をまとめてライブラリとして提供しています。

#### 入手

このGitHub内のNyanTimer/program/libraries/内の“NyanTimer”がライブラリです。このままダウンロードしてご自身のライブラリフォルダに入れて使ってください。

#### 必要なライブラリ

NyanTimerには前提として必要なライブラリがあります。以下のライブラリをインストールしておいてください。最近のArduinoライブラリではメニューバーの“スケッチ->ライブラリをインクルード->ライブラリを管理“から大抵のライブラリはインストールできますが、ST7032_SoftI2CMasterのみ私が改変したライブラリのため、NyanTimerライブラリと同じフォルダにあるライブラリをインストールしてください。

* TimerOne
  https://www.arduinolibraries.info/libraries/timer-one
* MsTimer2
  https://playground.arduino.cc/Main/MsTimer2/
* SoftI2CMaster
  https://github.com/felias-fogg/SoftI2CMaster
* ST7032_SoftI2CMaster
  https://ore-kb.net/archives/195 のものを私が改変しました。本GitHub内のprogram/librariesフォルダにあります。

#### 関数で使用する定数と変数

全ての定数と変数は以下のように使ってください。

```c++
NyanTimer::constantsOrVariables
```

関数として使っている定数と変数についての解説です。関数内でstaticになっているものは解説しません。

##### NyanTimerの各ピン

以下のものです

* **BUTTON1**
  リセットボタン
* **BUTTON2**
  モード切替ボタン
* **BUTTON3**
  ラップのカウントアップボタン
* **BUTTON4**
  ラップのカウントダウンボタン
* **BUZZER**
  ブザー(HIGHにするだけで勝手に鳴ります)
* **LEDR**
  赤色LED
* **LEDG**
  緑色LED
* **PAD1OUT**
  右パッドの出力ピン
* **PAD1IN**
  右パッドの入力ピン
* **PAD2OUT**
  左パッドの出力ピン
* **PAD2IN**
  左パッドの入力ピン

なお、PAD1OUT, PAD1IN, PAD2OUT, PAD2INについて、ユーザが直接触ることはないと思います。

##### 基礎的な変数

以下のものです。

* **int output[7]**
  シリアル出力やLCD出力をする際に時間情報を格納しておく配列。長さは7
* **char stat**
  ステータス情報。
* **int minute, second, msecond**
  時間。分秒ミリ秒
* **batterycount**
  自動バッテリー節約モードへの以降をするときに使う変数。

#### 関数の紹介

全ての関数は必ず

```c++
NyanTimer::function(argments);
```

の形で使ってください。

* **void begin(bool signal)**

NyanTimerの初期処理関数です。必ずvoid setup()の中で実行してください。引数は信号出力の有無(true: あり false: なし)

* **void timing()**

NyanTimerのタイマー処理の中枢です。必ずvoid loop等の定期的なループ内で実行してください。

* **void lightLED(int LED, bool HL)**

LEDを光らせる関数です。LEDにLEDGまたはLEDR、HLにtrue(点灯)またはfalse(消灯)を入力します。

* **void printLCD(int row, int col, String / char str)**

LCDになにか文字を表示する関数です。rowで表示する段(0か1)、colで表示開始列(0-15)を選択し、strを表示します。strはchar型でもString型でも動きます。

* **void startTimer(int msec, void function())**

タイマーをスタートさせる関数です。内部はMsTimer2の関数で構成されています。

msecにインターバルをミリ秒で入力し、functionに実行する関数を入力します。この関数を実行すると即座にタイマーがスタートします。

* **void stopTimer()**

タイマーをストップします。

* **int touch()**

タッチパッドの情報を得る関数です。

0: どちらのパッドもタッチされていない場合

1: 両方のパッドがタッチされている場合

2: 右パッドがタッチされている場合

3: 左パッドがタッチされている場合

* **void calcTime(int minute, int second, int msecond, int output)**

minute(分), second(秒), msecond(ミリ秒)の情報から、LCDへの出力に使いやすい時間配列を作ります。なお、output配列(長さ7)の内容を破壊的に変更します。

* **String strTime(int input[])**

input配列(長さ7)の情報から、LCDに出力する時に使うString文字列を作成します。

* **bool inputButton(int button)**

ボタンが押されればtrue、押されていなければfalseを返す関数です。

‘button’にBUTTON1などを入力します。

* **void setLCDclear(int mode)**

LCDを消去する関数です。mode == 0で上の行、1で下の行、2ですべての行がクリアされます。

* **void powersave()**

主電源を入れたままでパワーセーブモードに入る関数です。

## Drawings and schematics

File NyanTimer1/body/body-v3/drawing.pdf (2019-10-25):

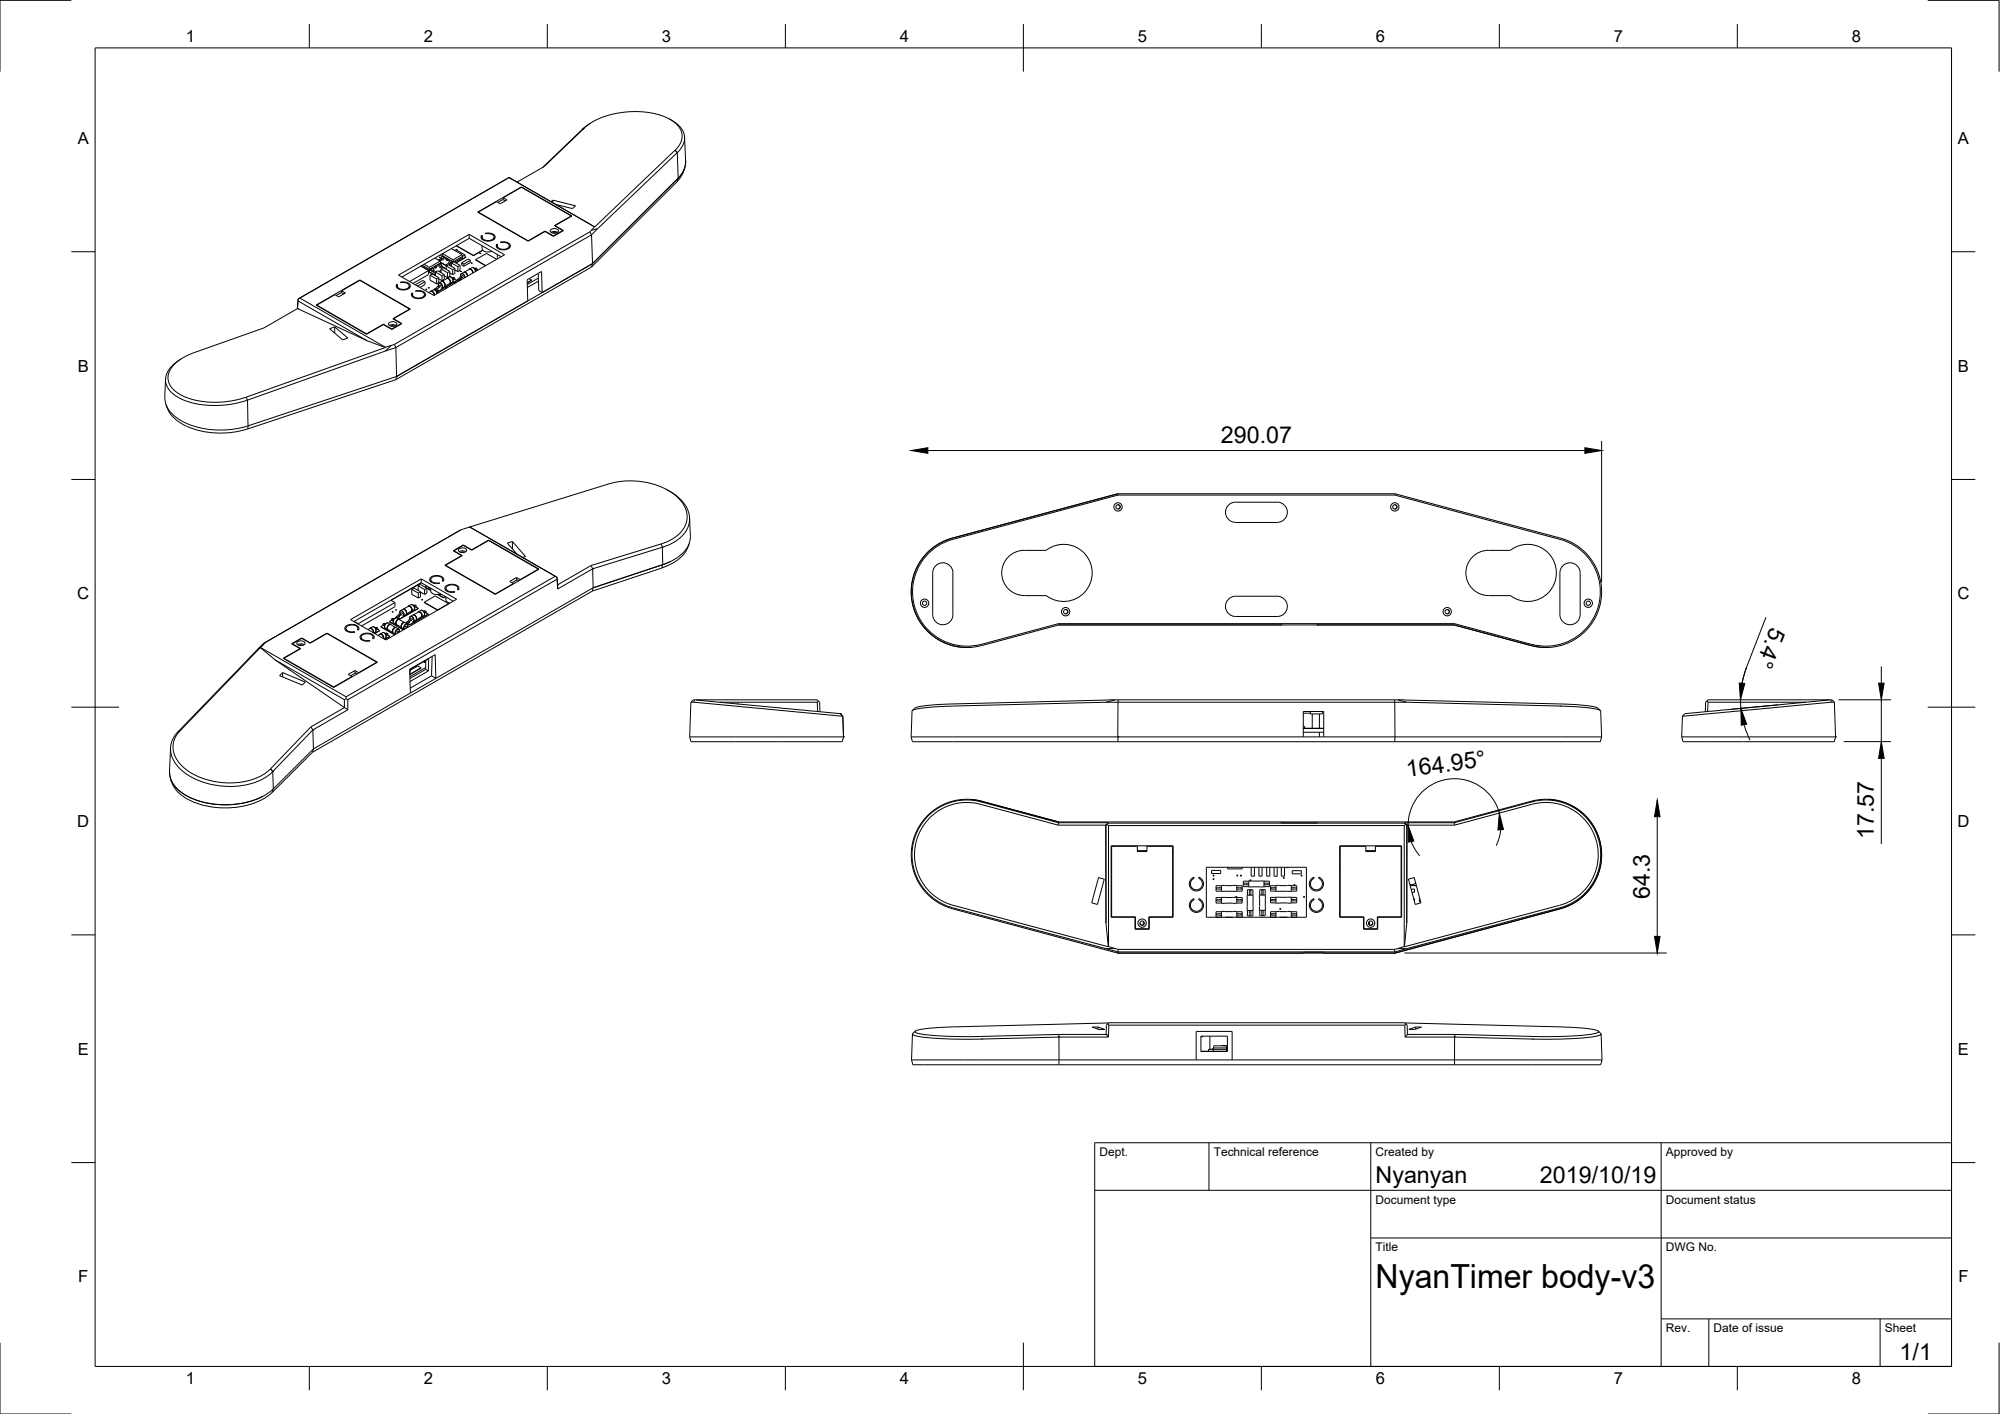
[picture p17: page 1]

Dept. | Technical reference | Created by 2019/10/19 | Approved by

Document type | Document status

Title NyanTimer body-v3 | DWG No.

Rev. | Date of issue | Sheet 1/1

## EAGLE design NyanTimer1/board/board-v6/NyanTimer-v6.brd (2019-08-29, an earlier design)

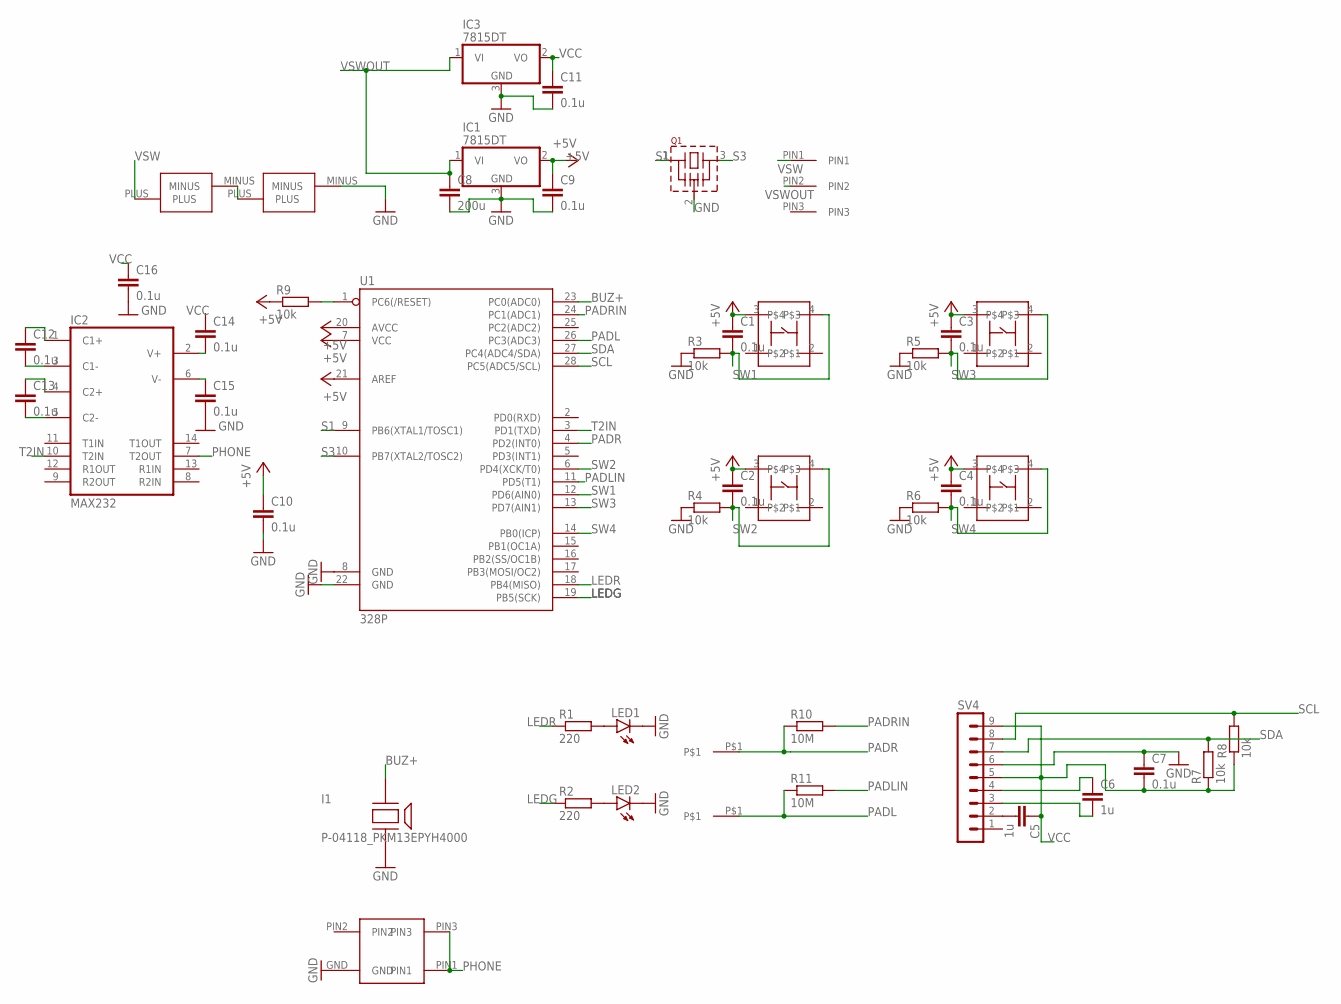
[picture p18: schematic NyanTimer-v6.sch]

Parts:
BT1, BT2: AKIZUKI_CR2032
C1, C2, C3, C4, C7, C9, C10, C11, C12, C13, C14, C15, C16: 0.1u; C025-024X044
C5, C6: 1u; C025-024X044
C8: 200u; C025-024X044
CONNECTOR1, CONNECTOR2, CONNECTOR3, CONNECTOR4: TACT_SWITCH
I1: P-04118_PKM13EPYH4000; PKM13EPYH4000
IC1, IC3: 7815DT; TO252
IC2: MAX232; DIL16
LED1, LED2: LED3MM
PHN1: PHONE
PIN1, PIN2: 1PINHEAD
Q1: CSTLA_T
R1, R2: 220; 0207/10
R3, R4, R5, R6, R7, R8, R9: 10k; 0207/10
R10, R11: 10M; 0207/10
SV4: MA09-1
SW1: AKIZUKI_SWITCH
U1: 328P; DIP28

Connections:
+5V: C1.1, C2.1, C3.1, C4.1, C9.1, C10.1, CONNECTOR1.3, CONNECTOR2.3, CONNECTOR3.3, CONNECTOR4.3, IC1.2 (VO), R9.1, U1.7 (VCC), U1.20 (AVCC), U1.21 (AREF)
BUZ+: I1.1, U1.23 (PC0(ADC0))
GND: BT2.MINUS, C7.1, C8.2, C9.2, C10.2, C11.2, C15.2, C16.2, I1.2, IC1.3 (GND), IC2.15 (GND), IC3.3 (GND), LED1.K (C), LED2.K (C), PHN1.GND, Q1.2 (VSS), R3.1, R4.1, R5.1, R6.1, SV4.6, U1.8 (GND), U1.22 (GND)
LEDG: R2.1, U1.19 (PB5(SCK))
LEDR: R1.1, U1.18 (PB4(MISO))
unnamed: LED1.A, R1.2
unnamed: LED2.A, R2.2
unnamed: C5.2, SV4.2
unnamed: C6.1, SV4.4
unnamed: C6.2, SV4.3
unnamed: BT1.MINUS, BT2.PLUS
unnamed: R9.2, U1.1 (PC6(/RESET))
unnamed: C12.2, IC2.3 (C1-)
unnamed: C12.1, IC2.1 (C1+)
unnamed: C13.1, IC2.4 (C2+)
unnamed: C13.2, IC2.5 (C2-)
unnamed: C14.2, IC2.2 (V+)
unnamed: C15.1, IC2.6 (V-)
PADL: PIN1.P$1, R11.1, U1.26 (PC3(ADC3))
PADLIN: R11.2, U1.11 (PD5(T1))
PADR: PIN2.P$1, R10.1, U1.4 (PD2(INT0))
PADRIN: R10.2, U1.24 (PC1(ADC1))
PHONE: IC2.7 (T2OUT), PHN1.PIN1, PHN1.PIN3
S1: Q1.1, U1.9 (PB6(XTAL1/TOSC1))
S3: Q1.3, U1.10 (PB7(XTAL2/TOSC2))
SCL: R8.2, SV4.8, U1.28 (PC5(ADC5/SCL))
SDA: R7.2, SV4.7, U1.27 (PC4(ADC4/SDA))
SW1: C1.2, CONNECTOR1.4, R3.2, U1.12 (PD6(AIN0))
SW2: C2.2, CONNECTOR2.4, R4.2, U1.6 (PD4(XCK/T0))
SW3: C3.2, CONNECTOR3.4, R5.2, U1.13 (PD7(AIN1))
SW4: C4.2, CONNECTOR4.4, R6.2, U1.14 (PB0(ICP))
T2IN: IC2.10 (T2IN), U1.3 (PD1(TXD))
VCC: C5.1, C7.2, C11.1, C14.1, C16.1, IC2.16 (VCC), IC3.2 (VO), R7.1, R8.1, SV4.5, SV4.9
VSW: BT1.PLUS, SW1.PIN1
VSWOUT: C8.1, IC1.1 (VI), IC3.1 (VI), SW1.PIN2

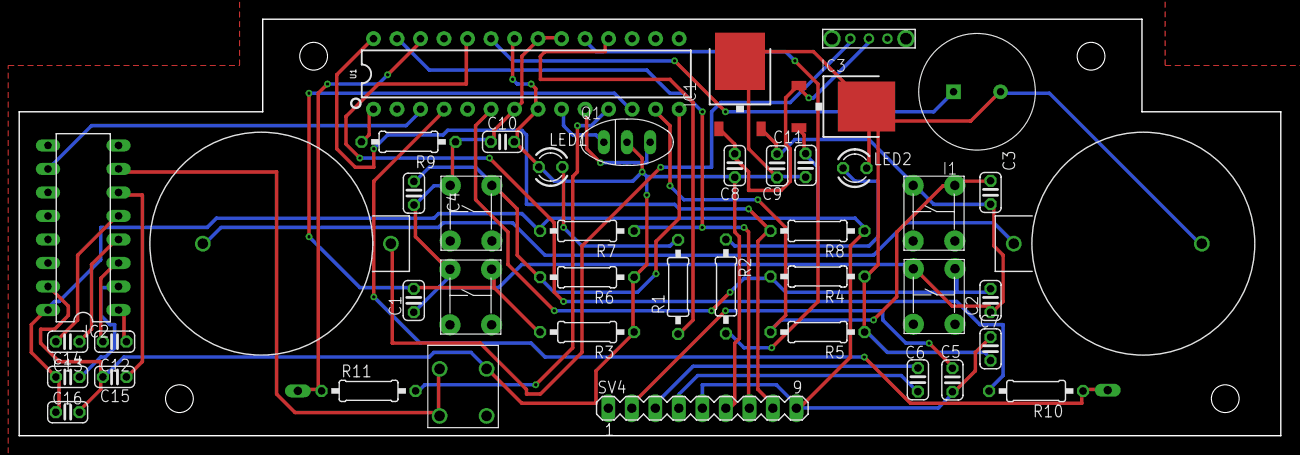
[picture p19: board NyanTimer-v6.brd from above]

Board: 2 copper layers, 136.3 x 45.0 mm, 46 parts (0 on the bottom side), 35 nets.

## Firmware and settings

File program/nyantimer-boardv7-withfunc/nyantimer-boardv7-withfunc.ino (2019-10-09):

#include "functions.h"

int minute, second, msecond = 0;
char stat = 'I'; //status
bool ledr = 0; //red led status
bool ledg = 0; //green led status
int inspmode = 0; //0:off 1:sndOFF 2:sndON
int lapmode = 1;
int lapcount = 0;
const int maxlap = 99;
int lap[maxlap + 1][3];
int inspstat = 0; //1=during inspstatection time
int inspstatcount = 16; //inspstatection time count
bool buz = 0;
long batterycount = 0;
const long batterythreshold = 60000; //1000 per 30s
String inspresult = "";

void setup() {
  resettime();
  NyanTimer::bgn();
  setLCDclear(2);
  lap[0][0] = 0;
  lap[0][1] = 0;
  lap[0][2] = 0;
}


void inspection() {
  inspstatcount--;
}




void count() { //every 1 msec
  msecond++;
  if (msecond == 1000) {
    msecond = 0;
    second++;
  }
  if (second == 60) {
    second = 0;
    minute++;
  }
  if (stat == ' ' && msecond % 100 == 0) {
    ledg = ledr;
    ledr = !ledr;
  }
  if (minute >= 100)
    NyanTimer::stopTimer();
  NyanTimer::calcTime(minute, second, msecond, NyanTimer::output);
}





void convertLCD() {
  String lcdouta = NyanTimer::strTime(NyanTimer::output);
  NyanTimer::printLCD(7, 0, lcdouta);

  String lcdoutb;
  if (lapcount >= 1) {
    int a[7];
    int t;
    if (stat == 'I')
      t = lapcount + 1;
    else
      t = lapcount;
    NyanTimer::calcTime(lap[t][0], lap[t][1], lap[t][2], a);
    lcdoutb = NyanTimer::strTime(a);
  } else
    lcdoutb = "         ";
  NyanTimer::printLCD(7, 1, lcdoutb);

  if (inspstat == 0) {
    if (inspmode == 1)
      NyanTimer::printLCD(0, 0, "I ");
    else if (inspmode == 2)
      NyanTimer::printLCD(0, 0, "Is");
    else if (inspmode == 0)
      NyanTimer::printLCD(0, 0, "  ");
  }
  NyanTimer::printLCD(0, 1, "L");
  NyanTimer::printLCD(1, 1, String(int(lapcount / 10)));
  NyanTimer::printLCD(2, 1, String(lapcount - int(lapcount / 10) * 10));
  NyanTimer::printLCD(3, 1, "/");
  NyanTimer::printLCD(4, 1, String(int(lapmode / 10)));
  NyanTimer::printLCD(5, 1, String(lapmode - int(lapmode / 10) * 10));
}



void convertLED() {
  NyanTimer::lightLED(LEDR, ledr);
  NyanTimer::lightLED(LEDG, ledg);
}



void resettime() {
  minute = 0;
  second = 0;
  msecond = 0;
  for (int i = 0; i < 7; i++)
    NyanTimer::output[i] = 0;
  for (int i = 0; i < maxlap; i++) {
    for (int j = 0; j < 3; j++)
      lap[i][j] = 0;
  }
  lapcount = 0;
}


void lapUP() {
  if (stat == 'I') {
    lapmode++;
    if (lapmode > maxlap)
      lapmode = 1;
  } else if (stat == 'S') {
    lapcount++;
    if (lapcount > lapmode) {
      lapcount = 1;
    }
  }
}

void lapDOWN() {
  if (stat == 'I') {
    lapmode--;
    if (lapmode < 1)
      lapmode = maxlap;
  } else if (stat == 'S') {
    lapcount--;
    if (lapcount < 1)
      lapcount = lapmode;
  }
}

void setLCDclear(int m) {
  if (m == 0 || m == 2) 
    NyanTimer::printLCD(0, 0, "                ");
  if (m == 1 || m == 2) 
    NyanTimer::printLCD(0, 1, "                ");
}

void button() {
  if (digitalRead(BUTTON1) == HIGH) {//reset
    int a = 0;
    int t = 500;
    while (digitalRead(BUTTON1) == HIGH) {
      a++;
      delay(1);
      if (a >= t)
        break;
    }
    if (a >= t) {
      NyanTimer::stopTimer();
      batterycount = 0;
      stat = 'I';
      inspresult = "";
      NyanTimer::printLCD(3, 0, "    ");
    }
  } else if (digitalRead(BUTTON2) == HIGH) { //inspstatection mode
    batterycount = 0;
    inspmode += 1;
    if (inspmode > 2)
      inspmode = 0;
    while (digitalRead(BUTTON2) == HIGH);
  } else if (digitalRead(BUTTON3) == HIGH) { //lap mode up
    batterycount = 0;
    lapUP();
    convertLCD();
    for (int i = 0; i < 1000; i++) {
      if (digitalRead(BUTTON3) == LOW)
        break;
      delay(1);
    }
    while (digitalRead(BUTTON3) == HIGH) {
      lapUP();
      delay(100);
      convertLCD();
    }
  } else if (digitalRead(BUTTON4) == HIGH) { //lap mode down
    batterycount = 0;
    lapDOWN();
    convertLCD();
    for (int i = 0; i < 1000; i++) {
      if (digitalRead(BUTTON4) == LOW)
        break;
      delay(1);
    }
    while (digitalRead(BUTTON4) == HIGH) {
      lapDOWN();
      delay(100);
      convertLCD();
    }
  } else if (stat == 'I')
    batterycount++;
}



void timer() {
  if (NyanTimer::touch(1) != 0) {
    if (stat == ' ') {

      bool tmp = false;
      if (lapcount == lapmode - 1 && NyanTimer::touch(0) == 1) { //when timer stops
        stat = 'S';
        NyanTimer::stopTimer();
        ledr = 0;
        ledg = 0;
        tmp = true;
      }

      if (lapcount < lapmode - 1 || tmp) { //lap++
        lapcount++;
        lap[lapcount][0] = minute;
        lap[lapcount][1] = second;
        lap[lapcount][2] = msecond;
        for (int i = lapcount - 1; i >= 0; i--) {
          lap[lapcount][0] -= lap[i][0];
          lap[lapcount][1] -= lap[i][1];
          lap[lapcount][2] -= lap[i][2];
          if (lap[lapcount][1] < 0) {
            lap[lapcount][1] += 60;
            lap[lapcount][0]--;
          }
          if (lap[lapcount][2] < 0) {
            if (lap[lapcount][1] == 0) {
              lap[lapcount][1] += 60;
              lap[lapcount][0]--;
            }
            lap[lapcount][2] += 1000;
            lap[lapcount][1]--;
          }
        }
        bool touchflag = true;
        int cnt = 0;
        int touchthreshold = 10;
        while (touchflag) {
          if (NyanTimer::touch(1) == 0)
            cnt++;
          else
            cnt = 0;
          if (cnt > touchthreshold)
            touchflag = false;
        }
      }


    } else if (stat == 'I' && NyanTimer::touch(0) == 1) { //timer ready to start
      if (inspmode == 0 || (inspmode == 1 && inspstat == 2) || (inspmode == 2 && inspstat == 2)) { //not inspstatection mode
        int i = 0;
        ledr = 1;
        ledg = 0;
        convertLED();
        int waitingthreshold = 20;
        while (NyanTimer::touch(0) == 1 && i < waitingthreshold) { //wait about 0.55sec
          i++;
          delay(1);
          if (inspmode == 2) {
            if (inspstatcount > 0 && inspstatcount < 16) {
              String inspstatcountstr = String(int(inspstatcount / 10)) + String(inspstatcount - 10 * int(inspstatcount / 10));
              NyanTimer::printLCD(3, 0, inspstatcountstr);
            } else if (inspstatcount > -2 && inspstatcount <= 0) {
              inspresult = "+2";
            } else if  (inspstatcount <= -2) {
              inspresult = "DNF";
              NyanTimer::printLCD(3, 0, "DNF");
              NyanTimer::stopTimer();
            }
            if (inspmode == 2) {
              if (inspstatcount == 7 || inspstatcount == 3)
                buz = 1;
              else
                buz = 0;
            } else
              buz = 0;
            digitalWrite(BUZZER, buz);
          }
        }
        if (i >= waitingthreshold)  //timer is able to start
          stat = 'A';
      } else if ((inspmode == 1 && inspstat == 0) || (inspmode == 2 && inspstat == 0)) { //inspstatection mode
        int i = 0;
        int waitingthreshold = 15;
        while (NyanTimer::touch(0) == 1 && i < waitingthreshold) { //wait about 0.55sec
          i++;
          delay(1);
        }
        if (i >= waitingthreshold) { //timer is able to start
          inspstat = 1;
          ledr = 1;
          ledg = 0;
        } else {
          ledr = 0;
          ledg = 0;
        }
        convertLED();
        while (NyanTimer::touch(0) == 1);
      }
    }
  }




  if (NyanTimer::touch(0) == 0) { //when pads are open

    if (stat == 'A') { //start solving
      stat = ' ';
      inspstat = 0;
      NyanTimer::stopTimer();
      NyanTimer::startTimer(1, count);

      setLCDclear(1);
      bool touchflag = true;
      int cnt = 0;
      int touchthreshold = 10;
      while (touchflag) {
        if (NyanTimer::touch(1) == 0)
          cnt++;
        else
          cnt = 0;
        if (cnt > touchthreshold)
          touchflag = false;
      }
    }

    else if (stat == 'I' && inspstat == 1) { //inspection time starts
      ledr = 1;
      ledg = 0;
      convertLED();
      inspstat = 2;
      NyanTimer::stopTimer();
      inspstatcount = 15;
      convertLCD();
      NyanTimer::startTimer(1000, inspection);
    }
  }


  if ((stat == 'I' && inspstat == 2) || (stat == 'A' && inspstat == 2)) {
    if (inspstatcount > 0 && inspstatcount < 16) {
      String inspstatcountstr = String(int(inspstatcount / 10)) + String(inspstatcount - 10 * int(inspstatcount / 10));
      NyanTimer::printLCD(3, 0, inspstatcountstr);
    } else if (inspstatcount > -2 && inspstatcount <= 0)
      inspresult = "+2";
    else if  (inspstatcount <= -2) {
      inspresult = "DNF";
      NyanTimer::stopTimer();
    }
    if (inspmode == 2) {
      if (inspstatcount == 7 || inspstatcount == 3)
        buz = 1;
      else
        buz = 0;
    } else
      buz = 0;

  } else
    buz = 0;
  digitalWrite(BUZZER, buz);
}



void loop() {
  button();
  if (stat == 'I' || stat == 'A') {
    resettime();
  }

  timer();

  if (stat != 'I') //autopower off unit
    batterycount = 0;
  if (batterycount >= batterythreshold) {
    setLCDclear(2);
    for (;;);
  }

  if (stat == 'S') {
    ledr = 0;
    ledg = 1;
  } else if (stat == 'A') {
    ledr = 1;
    ledg = 1;
  } else if (stat == 'I') {
    ledr = 0;
    ledg = 0;
  }

  if (stat == 'I' && NyanTimer::touch(1) == 2)
    NyanTimer::statout = 'R';
  else if (stat == 'I' && NyanTimer::touch(1) == 3)
    NyanTimer::statout = 'L';
  else
    NyanTimer::statout = String(stat);

  convertLCD();
  convertLED();
  NyanTimer::printLCD(3, 0, inspresult);
}

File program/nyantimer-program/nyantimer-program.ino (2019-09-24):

#include <MsTimer2.h>
#include <TimerOne.h>
#include <Wire.h>
#include <ST7032.h>

ST7032 lcd;

#define BUTTON1 6 //reset
#define BUTTON2 8 //inspection mode
#define BUTTON3 7 //lap up
#define BUTTON4 4 //lap down
#define BUZZER 14 //buzzer
#define LEDR 13 //red led
#define LEDG 12 //green led
#define PAD1OUT 15
#define PAD1IN 2
#define PAD2OUT 5
#define PAD2IN 17

int minute, second, msecond = 0;
int output[7] = {0, 0, 0, 0, 0, 0, 0};
char stat = 'I'; //status
bool ledr = 0; //red led status
bool ledg = 0; //green led status
int inspmode = 0; //0:off 1:sndOFF 2:sndON
int lapmode = 1;
int lapcount = 0;
const int maxlap = 99;
int lap[maxlap + 1][3];
int inspstat = 0; //1=during inspstatection time
int inspstatcount = 16; //inspstatection time count
bool buz = 0;
long batterycount = 0;
const long batterythreshold = 60000; //1000 per 30s
String statout;
String inspresult = "";
bool outmode = false;

void setup() {
  Serial.begin(1200);
  pinMode(BUTTON1, INPUT);
  pinMode(BUTTON2, INPUT);
  pinMode(BUTTON3, INPUT);
  pinMode(BUTTON4, INPUT);
  pinMode(BUZZER, OUTPUT);
  pinMode(LEDR, OUTPUT);
  pinMode(LEDG, OUTPUT);
  pinMode(PAD1OUT, OUTPUT);
  pinMode(PAD2OUT, OUTPUT);
  pinMode(PAD1IN, INPUT);
  pinMode(PAD2IN, INPUT);
  lcd.begin(16, 2);
  lcd.setContrast(40);

  resettime();

  lcd.setCursor(0, 0); //when power is off: print "Nyan Timer"
  lcd.print("NyanTimer       ");
  lcd.setCursor(0, 1);
  lcd.print("      by Nyanyan");
  delay(1000);
  setLCDclear(2);
  lap[0][0] = 0;
  lap[0][1] = 0;
  lap[0][2] = 0;
}


void out() { //serial output, every 125msec
  String serout = statout;

  for (int i = 1; i < 7; i++)
    serout += output[i];
  int tmp = 0;
  for (int i = 1; i < 7; i++) {
    tmp += output[i];
  }
  char checksum = 64 + tmp;
  serout += String(checksum);
  Serial.print(serout);
  Serial.print(char(13));
  Serial.print(char(10));
}


void inspection() {
  inspstatcount--;
}




void count() { //every 1 msec
  msecond++;
  if (msecond == 1000) {
    msecond = 0;
    second++;
  }
  if (second == 60) {
    second = 0;
    minute++;
  }
  if (stat == ' ' && msecond % 100 == 0) {
    ledg = ledr;
    ledr = !ledr;
  }
  if (minute >= 100)
    Timer1.stop();
  output[0] = int(minute / 10);
  output[1] = minute - output[0] * 10;
  output[2] = int(second / 10);
  output[3] = second - output[2] * 10;
  output[4] = int(msecond / 100);
  output[5] = int(msecond / 10) - output[4] * 10;
  output[6] = msecond - output[4] * 100 - output[5] * 10;
}





void convertLCD() {
  lcd.setCursor(7, 0); //print time
  String lcdouta = String(output[0]) + String(output[1]) + ':' + String(output[2]) + String(output[3]) + '.' + String(output[4]) + String(output[5]) + String(output[6]);
  lcd.print(lcdouta);

  lcd.setCursor(7, 1); //print lap time
  String lcdoutb;
  if (lapcount >= 1) {
    int a[7];
    int t;
    if (stat == 'I')
      t = lapcount + 1;
    else
      t = lapcount;
    a[0] = lap[t][0] / 10;
    a[1] = lap[t][0] - a[0] * 10;
    a[2] = lap[t][1] / 10;
    a[3] = lap[t][1] - a[2] * 10;
    a[4] = lap[t][2] / 100;
    a[5] = lap[t][2] / 10 - a[4] * 10;
    a[6] = lap[t][2] - a[4] * 100 - a[5] * 10;
    lcdoutb = String(a[0]) + String(a[1]) + ':' + String(a[2]) + String(a[3]) + '.' + String(a[4]) + String(a[5]) + String(a[6]);
  } else
    lcdoutb = "         ";
  lcd.print(lcdoutb);

  if (inspstat == 0) {
    lcd.setCursor(0, 0); //print mode & status
    if (inspmode == 1)
      lcd.print("I ");
    else if (inspmode == 2)
      lcd.print("Is");
    else if (inspmode == 0)
      lcd.print("  ");
  }

  lcd.setCursor(2, 0);
  if (outmode)
    lcd.print("o");
  else
    lcd.print(" ");

  lcd.setCursor(0, 1);
  lcd.print("L");
  lcd.setCursor(1, 1);
  lcd.print(int(lapcount / 10));
  lcd.setCursor(2, 1);
  lcd.print(lapcount - int(lapcount / 10) * 10);
  lcd.setCursor(3, 1);
  lcd.print("/");
  lcd.setCursor(4, 1);
  lcd.print(int(lapmode / 10));
  lcd.setCursor(5, 1);
  lcd.print(lapmode - int(lapmode / 10) * 10);
}



void convertLED() {
  digitalWrite(LEDR, ledr);
  digitalWrite(LEDG, ledg);
}




int touch(int mode) {
  float threshold = 20;
  if (outmode)
    threshold = 150;
  float t = 15;
  if (outmode)
    t = 2;
  float k = 0.5;
  float VAL1 = 0;
  float VAL2 = 0;

  for (int i = 0; i < t; i++) {
    float val1 = 0;
    float val2 = 0;
    digitalWrite(PAD1OUT, HIGH);
    while (digitalRead(PAD1IN) == LOW) {
      val1++;
      if (val1 > threshold)
        break;
    }
    digitalWrite(PAD1OUT, LOW);

    digitalWrite(PAD2OUT, HIGH);
    while (digitalRead(PAD2IN) == LOW) {
      val2++;
      if (val2 > threshold)
        break;
    }
    digitalWrite(PAD2OUT, LOW);

    if (val1 > 0 && val2 > 0) {
      VAL1 += val1;
      VAL2 += val2;
    } else
      i--;

    delayMicroseconds(100);
  }
  if (mode == 0) {
    if (VAL1 > threshold * t * k && VAL2 > threshold * t * k)
      return 1;
    else
      return 0;
  } else {
    if (VAL1 > threshold * t * k && VAL2 > threshold * t * k)
      return 1;
    else if (VAL1 >= threshold * t * k && VAL2 < threshold * t * k)
      return 2;
    else if (VAL1 < threshold * t * k && VAL2 >= threshold * t * k)
      return 3;
    else
      return 0;
  }
}

void resettime() {
  minute = 0;
  second = 0;
  msecond = 0;
  for (int i = 0; i < 7; i++)
    output[i] = 0;
  for (int i = 0; i < maxlap; i++) {
    for (int j = 0; j < 3; j++)
      lap[i][j] = 0;
  }
  lapcount = 0;
}


void lapUP() {
  if (stat == 'I') {
    lapmode++;
    if (lapmode > maxlap)
      lapmode = 1;
  } else if (stat == 'S') {
    lapcount++;
    if (lapcount > lapmode) {
      lapcount = 1;
    }
  }
}

void lapDOWN() {
  if (stat == 'I') {
    lapmode--;
    if (lapmode < 1)
      lapmode = maxlap;
  } else if (stat == 'S') {
    lapcount--;
    if (lapcount < 1)
      lapcount = lapmode;
  }
}

void setLCDclear(int m) {
  if (m == 0 || m == 2) {
    lcd.setCursor(0, 0);
    lcd.print("                ");
  }
  if (m == 1 || m == 2) {
    lcd.setCursor(0, 1);
    lcd.print("                ");
  }
}
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

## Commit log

2019-07-11 名称変更
2019-07-11 add board-v5
    [NyanTimer-v5.brd, NyanTimer-v5.sch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]
2019-07-11 added document and old board
    [NyanTimer-v4.brd, NyanTimer-v4.sch]
2019-07-11 modified board
    [NyanTimer-v5.brd]
2019-07-12 modified readme and created gerber file
2019-07-15 created 3d model
    [NyanTimer_hardware.stl]
2019-07-16 updated 3d models
    [NyanTimer_hardware.obj, NyanTimer_hardware.stl]
2019-07-17 renamed hardware folder
    [NyanTimer_hardware.obj, NyanTimer_hardware.stl]
2019-07-17 deleted some gerber files
    [copper_bottom.gbr, copper_top.gbr, drill_1_16.xln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]
2019-07-18 modified program for 3.3 voltage
2019-07-18 modified README and added imaes
    [NyanTimer-v5.sch]
2019-07-19 updated 3d models and modified program
    program: modified threshold of touchpad
    [NyanTimer_hardware.obj, NyanTimer_hardware.stl]
2019-07-21 added board-v6
    [NyanTimer-v6.brd, NyanTimer-v6.sch]
2019-07-28 add power off unit
2019-07-29 set auto-power-off time 1h
2019-08-27 modified holes
    [NyanTimer_hardware.obj, NyanTimer_hardware.stl]
2019-08-29 modified and ordered boards
    [NyanTimer-v6.brd, NyanTimer-v6.sch]
2019-08-30 TBD parts list
    [parts.xlsx]
2019-08-30 DONE parts list
    [parts.xlsx]
2019-08-30 created nc file: right boards
2019-08-31 modified folder name
    [parts.xlsx]
2019-08-31 modified folder tree
    [NyanTimer-v4.brd, NyanTimer-v4.sch, NyanTimer-v5.brd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]
2019-09-03 modified parts list
    [parts.xlsx]
2019-09-03 changed name
    [parts.xlsx]
2019-09-05 modified readme: checked board-v6
2019-09-22 reset to push button for 1 sec
    [nyantimer-program.ino]
2019-09-22 modified batterycount
2019-09-22 modified touch sensor threshold
2019-09-23 switch serial out mode
2019-09-23 changed swiching serial button
2019-09-23 calibration modified
2019-09-24 modified power on touch voltage
2019-09-25 created board-v7
    [NyanTimer-v7.brd, NyanTimer-v7.sch]
2019-09-25 modified padl pin
    [NyanTimer-v7.brd, NyanTimer-v7.sch]
2019-09-25 created garber
    [NyanTimer-v7.GTS]
2019-09-25 created body-v2 folder
    [NyanTimer-v7.brd, NyanTimer_hardware.obj, NyanTimer_hardware.stl]
2019-09-25 add body-v2 files
    [body-v2.stl]
2019-09-26 deleted GTS
    [NyanTimer-v7.GTS]
2019-09-26 mounted USB-Serial pinhead
    [NyanTimer-v7.brd, NyanTimer-v7.sch]
2019-09-26 changed pad
    [NyanTimer-v7.brd, NyanTimer-v7.sch]
2019-09-26 modified & made garber
    [NyanTimer-v7.brd]
2019-09-26 modfied 3d models
    [body-v2.stl]
2019-09-28 light LED while inspection time
2019-10-03 modified readme: board v7
2019-10-06 lib timer
2019-10-06 modified program: lib timer
2019-10-06 modified lib: timer
2019-10-06 modified led
2019-10-10 modified readme
    [上.stl]
2019-10-11 modified stl
    [上.stl]
2019-10-12 deleted body v3
    [上.stl, 下.stl]
2019-11-05 fixed button bug
2019-11-05 auto power off works
2019-11-05 deleted memory print
2019-11-08 buzzing alert when +2 and DNF
    [nyantimer-boardv7-withlib.ino]
2019-11-17 modified timer start
2019-11-20 deleted comments
    [parts.xlsx]
2019-11-26 dont reset time if power off without reset
    [nyantimer-boardv7-withlib.ino]
2020-01-16 changed dir
    [NyanTimer-v4.brd, NyanTimer-v4.sch, NyanTimer-v5.brd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]
2020-01-16 make file and sample program
2020-01-16 mount start and stop
2020-01-16 mount timing
2020-01-16 save time
    [data.csv]
2020-01-16 ao5 and ao12, bests
    [data.csv]
2020-01-16 best single
    [data.csv, data3x3.csv]
2020-01-16 status: ao50,100,1000
    [data3x3.csv]
2020-01-16 ao50 and ao1000
    [data3x3.csv]
2020-01-16 modified ao50/100
    [data3x3.csv]
2020-01-16 added data files
    [data3x3.csv]
2020-01-16 index and del
    [data2x2.csv, data3BLD.csv, data3OH.csv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]
2020-01-17 change session
    [data3x3.csv]
2020-01-17 mount func of change session
2020-01-17 fix bug
    [data2x2.csv, data3BLD.csv, data3OH.csv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]
2020-01-25 fixed session change bug
    [data3x3.csv]
2020-01-25 calc time aox list
    [data3x3.csv]
2020-01-25 view time
    [data3x3.csv]
2020-01-31 show time during time list
    [data3x3.csv]
2020-02-01 banned waiting threshold, use millis()
2020-02-04 arduino program
2020-02-05 TBD mounting serial
2020-02-05 TBD calctime
    [data2x2.csv, data3BLD.csv, data3OH.csv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]
2020-03-30 inspection TBD
    [data2x2.csv, data3BLD.csv, data3OH.csv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]
2020-03-31 mount +2 and DNF TBD

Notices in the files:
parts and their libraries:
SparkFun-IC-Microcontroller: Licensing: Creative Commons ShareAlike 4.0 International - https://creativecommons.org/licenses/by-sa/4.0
